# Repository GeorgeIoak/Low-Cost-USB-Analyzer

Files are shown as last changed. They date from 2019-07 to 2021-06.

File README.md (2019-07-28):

# Low Cost High Speed USB Analyzer
This project originated starting from a comment made by Kate Temkin (@ktemkin) with the idea to design a very low cost USB analyzer that was capable of achieving HS (High Speed). The [NXP LPC4357 MCU (32-bit ARM Cortex-M4/M0 MCU)](https://www.nxp.com/docs/en/data-sheet/LPC435X_3X_2X_1X.pdf) can operate at up to 204MHz and has (among other things) a ULPI interface. The [Microchip USB3343](http://ww1.microchip.com/downloads/en/DeviceDoc/USB334x-Data-Sheet-DS00002646A.pdf) is used as the interface between the USB device to test and the LPC4357. The LPC4357 has a 2nd HS USB port that can connect to a PC for USB traffic analysis. The board also includes a 256Mb SDR SDRAM.

In order to keep costs down the size of the board was fixed at 50mm x 50mm and 4 layers. This is far from ideal when doing a controlled impedance design with this many signals so there are some tradeoffs. I didn't want to waste all of the processing capabilities so I managed to bring out ALL of the LPC4357 signals to 1.27mm pitch headers around the perimiter of the PCB. The 24-bit LCD interface signals are all on 1 header and the Ethernet signals are all on another header.

This is NOT a finished project but it is getting close. The design in done in Altium but I am going to try and convert the design to KiCad once it gets closer to being finished

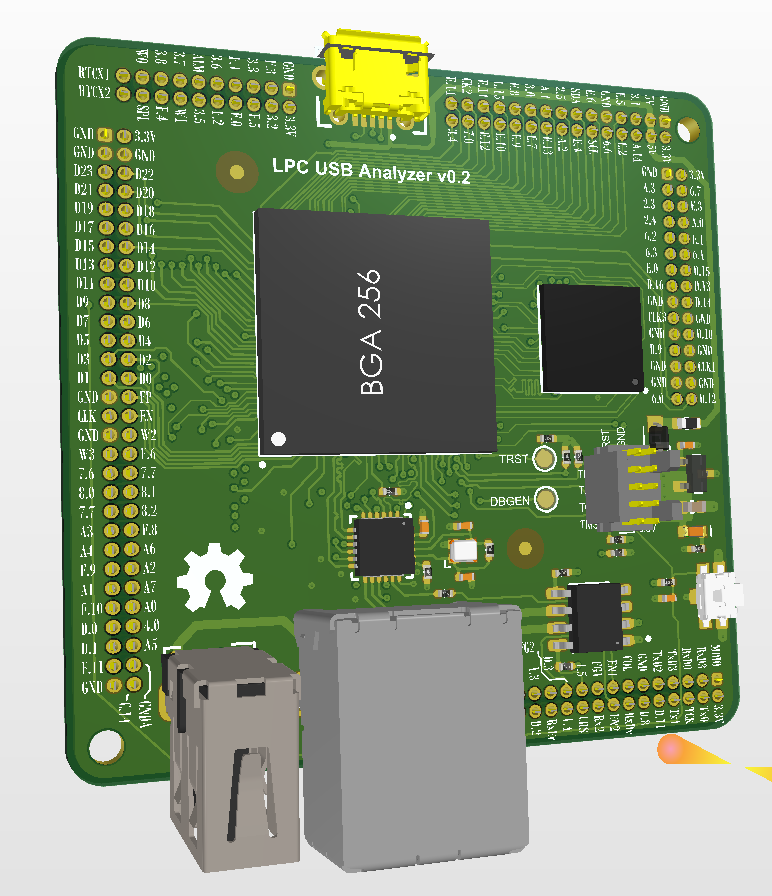
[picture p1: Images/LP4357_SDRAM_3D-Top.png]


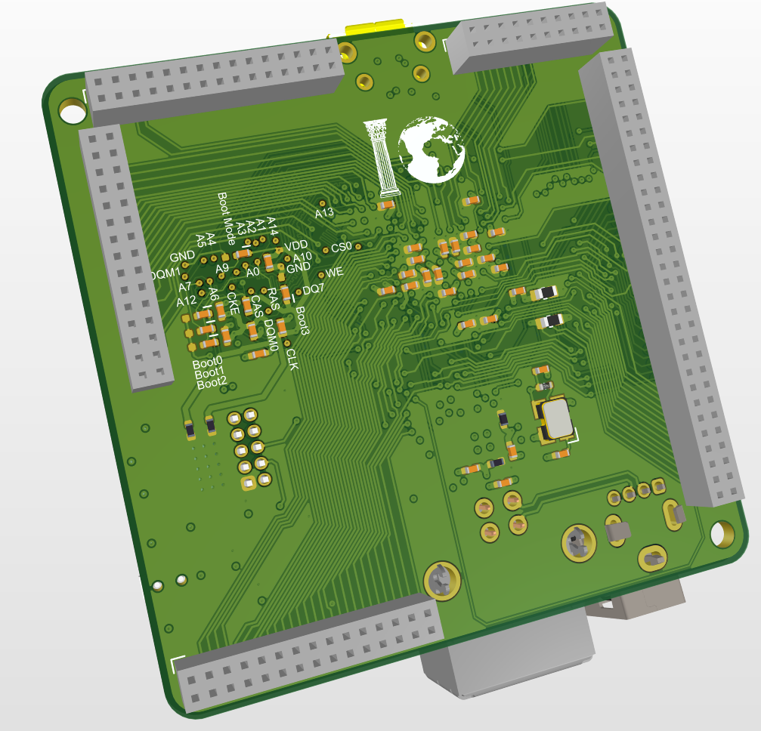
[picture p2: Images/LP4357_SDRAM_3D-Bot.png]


You can download the "LPC4357_SDRAM-BGA Design Files.zip" file and use [Altium's Online Viewer](https://www.altium.com/viewer?utm_content=buffer67ff0) to look through the schematic and layout

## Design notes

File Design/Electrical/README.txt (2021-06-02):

R1 and R11 were purchased as 8.06Ω instead of 8.06kΩ so the prototypes were built with the wrong part.

R1 is on the RBIAS pin of the USB3343 so that's important to change
R11 is just LED series resistor for 3.3V power indicator

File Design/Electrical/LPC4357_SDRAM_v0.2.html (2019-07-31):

Altium customize

# Board Information Report

Date: | | 7/30/2019
Time: | | 5:17:31 PM
Elapsed Time: | | 00:00:00
Filename: | | C:\Users\georg\Dropbox\Design\LPC4357_SDRAM\Design\Electrical\LPC4357_SDRAM_v0.2.PcbDoc
Units: | | mmmils

## Contents

Contents

Board Specification

General

Routing

Routing Information

Layer Information

Layer Information

Drill Pairs

Board Holes

Non-Plated Hole Size

Plated Hole Size

Board Slots

Non-Plated Slot Size

Plated Slot Size

Board Square Holes

Non-Plated Square Hole Size

Plated Square Hole Size

Other

Top Layer Annular Ring Size

Mid Layer Annular Ring Size

Bottom Layer Annular Ring Size

Pad Solder Mask

Pad Paste Mask

Pad Pwr/Gnd Expansion

Pad Relief Conductor Width

Pad Relief Air Gap

Pad Relief Entries

Via Solder Mask

Via Pwr/Gnd Expansion

Track Width

Arc Line Width

Arc Radius

Arc Degrees

Text Height

Text Width

Net Track Width

Net Via Size

## Board Specification

General
Board Size | 50mm x 50mm
Components on board | 90

Back to top

## Routing

Routing Information
Routing completion | 100.00%
Connections | 472
Connections routed | 472
Connections remaining | 0

Back to top

## Layer Information

Layer | Arcs | Pads | Vias | Tracks | Texts | Fills | Regions | ComponentBodies
Top Layer | 65 | 412 | 0 | 1606 | 0 | 1 | 485 | 0
Int1 (GND) | 0 | 0 | 0 | 0 | 0 | 0 | 1 | 0
Int2 (PWR) | 414 | 0 | 0 | 1209 | 0 | 0 | 135 | 0
Bottom Layer | 0 | 101 | 0 | 1342 | 0 | 0 | 328 | 0
Board Outline | 4 | 0 | 0 | 4 | 0 | 0 | 0 | 2
Top 3D Bodies | 2 | 0 | 0 | 17 | 0 | 0 | 0 | 80
Mechanical 12 | 0 | 0 | 0 | 0 | 0 | 0 | 0 | 0
Mechanical 13 | 4 | 0 | 0 | 269 | 1 | 0 | 0 | 5
Mechanical 15 | 2 | 0 | 0 | 469 | 2 | 0 | 0 | 1
Mechanical 16 | 0 | 0 | 0 | 2 | 0 | 0 | 0 | 0
Mechanical 22 | 0 | 0 | 0 | 0 | 0 | 0 | 0 | 0
Multi-Layer | 0 | 201 | 346 | 0 | 0 | 0 | 1 | 0
Top Paste | 0 | 0 | 0 | 0 | 0 | 9 | 0 | 0
Top Overlay | 8 | 0 | 0 | 83 | 255 | 0 | 2 | 0
Top Solder | 0 | 0 | 0 | 0 | 0 | 0 | 0 | 0
Bottom Solder | 0 | 0 | 0 | 0 | 0 | 0 | 0 | 0
Bottom Overlay | 0 | 0 | 0 | 3043 | 135 | 0 | 0 | 0
Bottom Paste | 0 | 0 | 0 | 0 | 0 | 0 | 0 | 0
Drill Guide | 0 | 0 | 0 | 0 | 0 | 0 | 0 | 0
Keep-Out Layer | 4 | 0 | 0 | 4 | 0 | 0 | 0 | 0
Drill Drawing | 0 | 0 | 0 | 173 | 104 | 0 | 0 | 0
Total | 503 | 714 | 346 | 8221 | 497 | 10 | 952 | 88

Back to top

Drill Pairs | Vias
Top Layer - Bottom Layer | 346
Total | 346

Back to top

## Board Holes

Non-Plated Hole Size | Pads | Vias
0mm | 13 | 0
Total | 13 | 0

Back to top

Plated Hole Size | Pads | Vias
0mm | 500 | 0
0.2mm | 0 | 327
0.25mm | 0 | 15
0.3mm | 0 | 4
0.6mm | 170 | 0
0.7mm | 12 | 0
0.8mm | 4 | 0
0.9mm | 2 | 0
0.92mm | 4 | 0
1.2mm | 2 | 0
2mm | 1 | 0
2.2mm | 1 | 0
2.3mm | 2 | 0
Total | 698 | 346

Back to top

## Board Slots

Non-Plated Slot Size / Length | Pads
Total | 0

Back to top

Plated Slot Size / Length | Pads
23.622mil / 70.866mil | 2
39.37mil / 62.992mil | 1
Total | 3

Back to top

## Board Square Holes

Non-Plated Square Hole Size | Pads
Total | 0

Back to top

Plated Square Hole Size | Pads
Total | 0

Back to top

## Other

Top Layer Annular Ring Size | Count
-10.7mm | 2
-1.2mm | 1
-1mm | 1
0.2mm | 4
0.25mm | 352
0.3mm | 4
0.3mm | 170
0.497mm | 2
0.58mm | 4
0.6mm | 2
0.7mm | 2
1.6mm | 1
2mm | 2
Total | 547

Back to top

Mid Layer Annular Ring Size | Count
-10.7mm | 2
-1.2mm | 1
-1mm | 1
0.2mm | 4
0.25mm | 352
0.3mm | 4
0.3mm | 170
0.497mm | 2
0.58mm | 4
0.6mm | 2
0.7mm | 2
1.6mm | 1
2mm | 2
Total | 547

Back to top

Bottom Layer Annular Ring Size | Count
-10.7mm | 2
-1.2mm | 1
-1mm | 1
0.2mm | 4
0.25mm | 352
0.3mm | 4
0.3mm | 170
0.497mm | 2
0.58mm | 4
0.6mm | 2
0.7mm | 2
1.6mm | 1
2mm | 2
Total | 547

Back to top

Pad Solder Mask | Count
0mm | 13
0.0508mm | 16
0.065mm | 24
0.07mm | 11
0.075mm | 310
0.09mm | 4
0.095mm | 4
0.1016mm | 330
1mm | 2
Total | 714

Back to top

Pad Paste Mask | Count
-10mm | 1
-2mm | 2
0mm | 709
0.1mm | 2
Total | 714

Back to top

Pad Pwr/Gnd Expansion | Count
0.508mm | 714
Total | 714

Back to top

Pad Relief Conductor Width | Count
0.254mm | 714
Total | 714

Back to top

Pad Relief Air Gap | Count
0.254mm | 714
Total | 714

Back to top

Pad Relief Entries | Count
4 | 714
Total | 714

Back to top

Via Solder Mask | Count
0.07mm | 4
0.1016mm | 342
Total | 346

Back to top

Via Pwr/Gnd Expansion | Count
0.508mm | 346
Total | 346

Back to top

Track Width | Count
0.01mm | 4
0.05mm | 264
0.0508mm | 3021
0.1mm | 1565
0.1016mm | 14
0.11mm | 595
0.127mm | 153
0.15mm | 774
0.152mm | 712
0.1524mm | 380
0.1778mm | 63
0.2mm | 26
0.2032mm | 167
0.254mm | 24
0.3mm | 25
0.4mm | 125
0.45mm | 237
0.452mm | 6
0.5mm | 39
0.508mm | 6
0.55mm | 1
0.6mm | 10
0.762mm | 4
0.8mm | 5
1mm | 1
Total | 8221

Back to top

Arc Line Width | Count
0.01mm | 2
0.0762mm | 2
0.1mm | 412
0.11mm | 44
0.127mm | 4
0.152mm | 29
0.25mm | 5
0.6mm | 1
0.762mm | 4
Total | 503

Back to top

Arc Radius | Count
0.0196mm | 2
0.03mm | 1
0.0301mm | 1
0.04mm | 318
0.044mm | 23
0.0504mm | 20
0.052mm | 10
0.0608mm | 29
0.069mm | 30
0.0704mm | 45
0.0911mm | 1
0.125mm | 4
0.3mm | 3
0.5mm | 4
0.635mm | 2
0.91mm | 2
2.5mm | 6
2.5mm | 2
Total | 503

Back to top

Arc Degrees | Count
78 | 2
90 | 487
360 | 14
Total | 503

Back to top

Text Height | Count
0.75mm | 1
0.762mm | 1
1mm | 121
1.4mm | 170
1.5mm | 1
1.524mm | 200
1.5494mm | 2
5mm | 1
Total | 497

Back to top

Text Width | Count
0.075mm | 1
0.127mm | 1
0.2032mm | 185
0.254mm | 310
Total | 497

Back to top

Net Track Width | Count
0.089mm | 229
0.254mm | 4
Total | 233

Back to top

Net Via Size | Count
0.45mm | 233
Total | 233

Back to top

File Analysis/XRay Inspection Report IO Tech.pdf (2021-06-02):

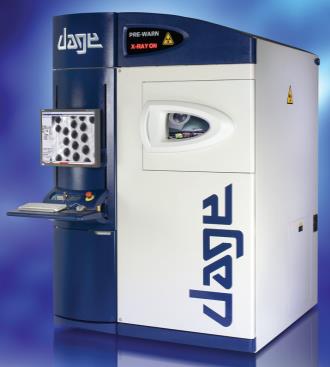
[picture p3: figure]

# X-Ray Inspection Report

Customer: | I/O SAFE

Work Order:

Assembly No:

Serial No:

Scope of work: | Inspecting BGA Balls
Engineer: | Victor Dallago
Date: | 08/15/2019
Observation/Conclusions | Varying size and shape of BGA balls caused by design of BGA pad layout

10030 Foothills Blvd.
Roseville, CA 95747
(800) 550-6005
www.prideindustries.com

# I/O SAFE

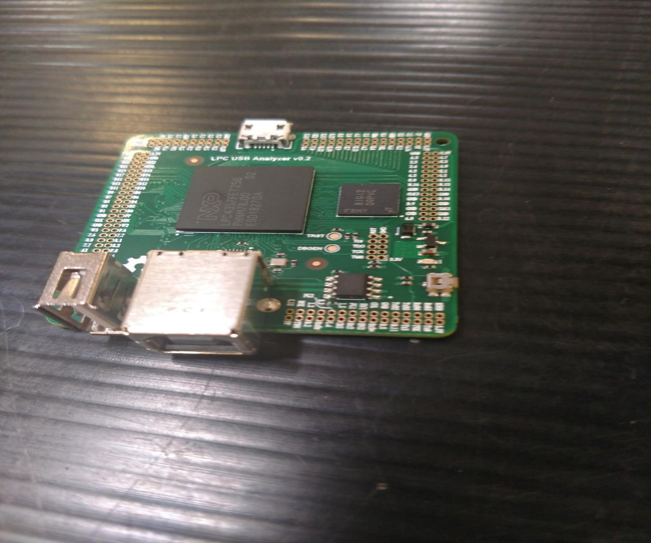
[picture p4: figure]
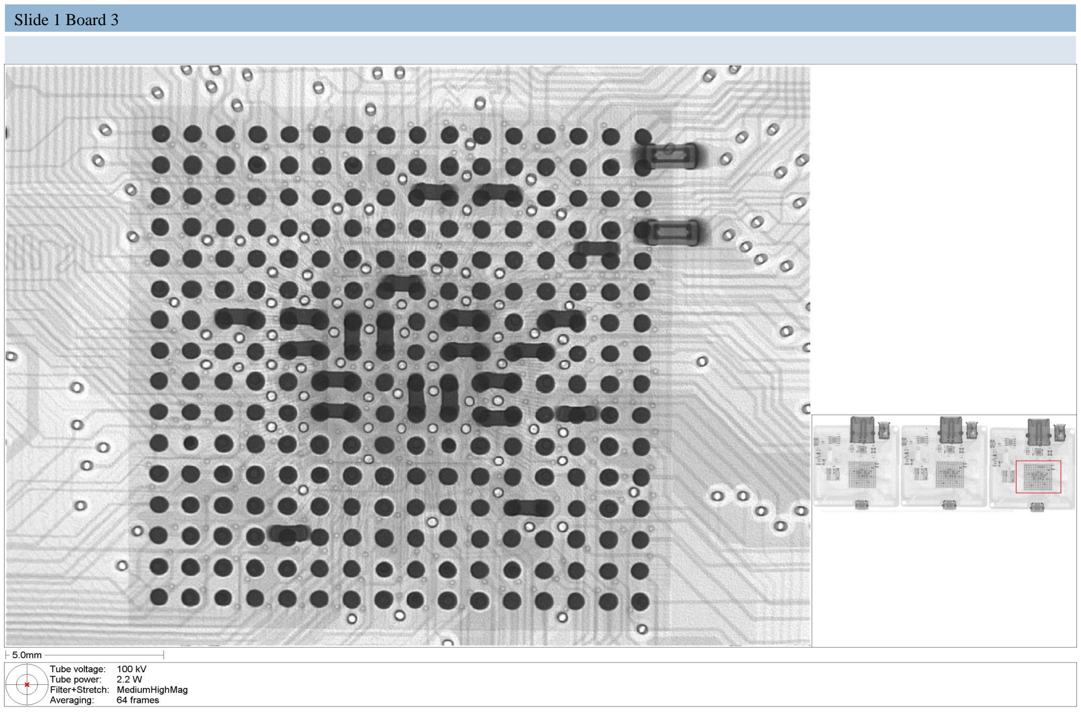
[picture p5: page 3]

Slide 1 Board 3

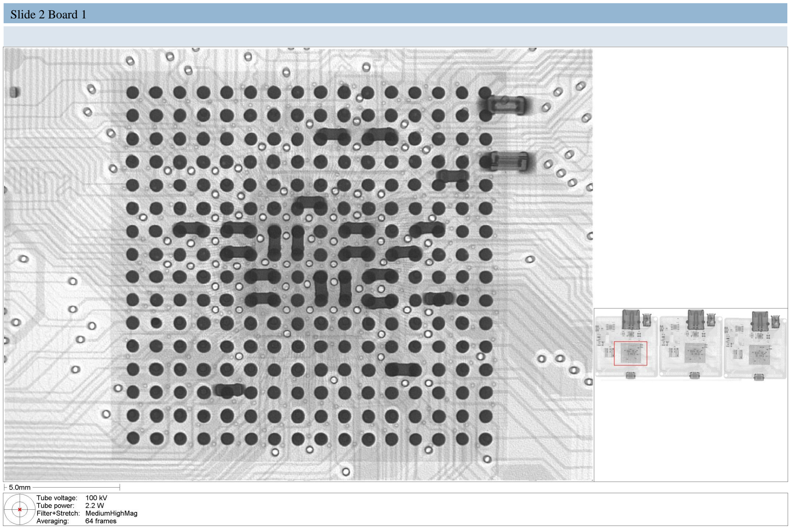
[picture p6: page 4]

Slide 2 Board 1

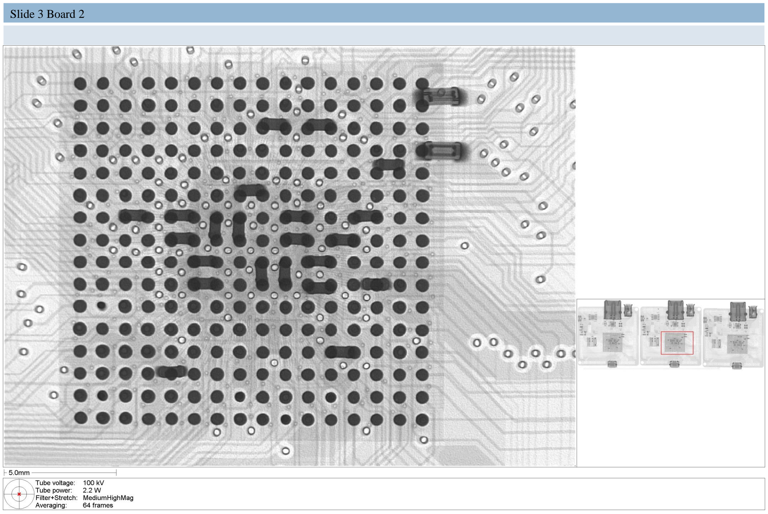
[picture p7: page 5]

Slide 3 Board 2

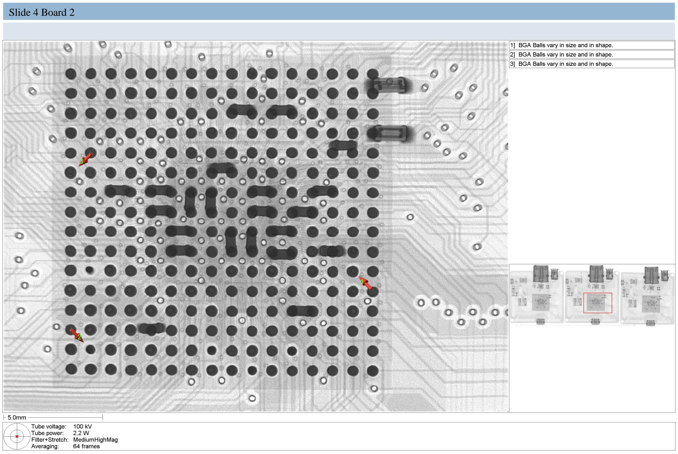
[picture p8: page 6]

Slide 4 Board 2

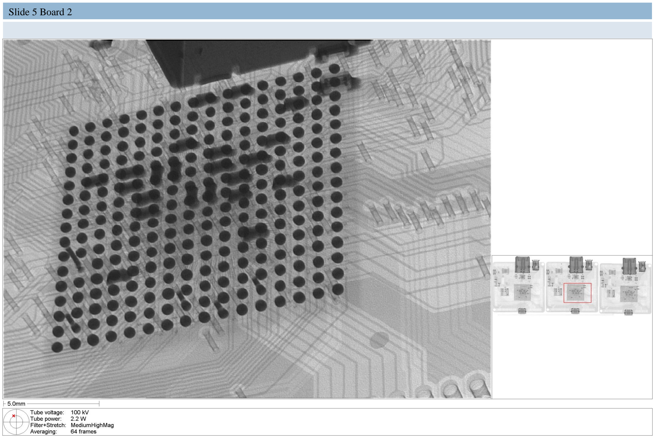
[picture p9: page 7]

Slide 5 Board 2

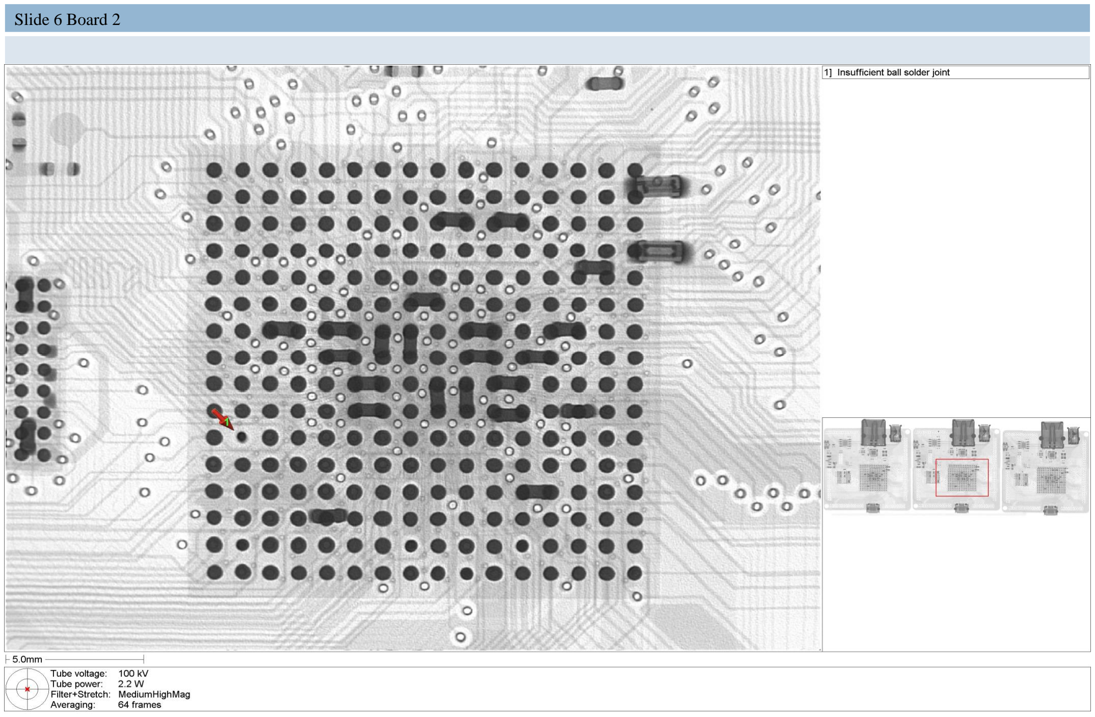
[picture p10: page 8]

Slide 6 Board 2

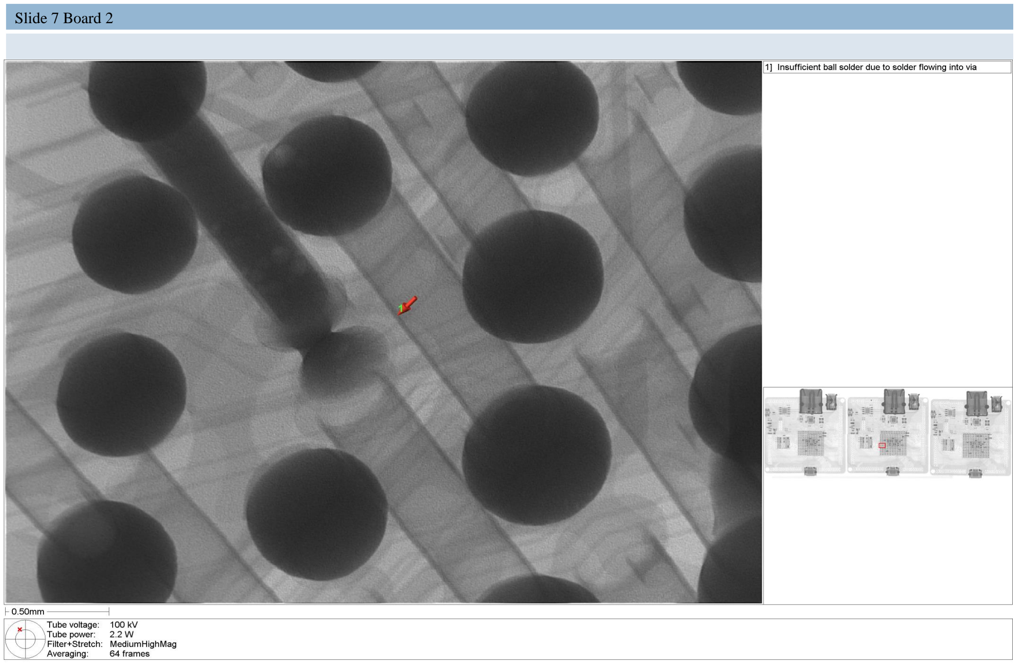
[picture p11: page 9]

Slide 7 Board 2

# 3D X-Ray Solutions

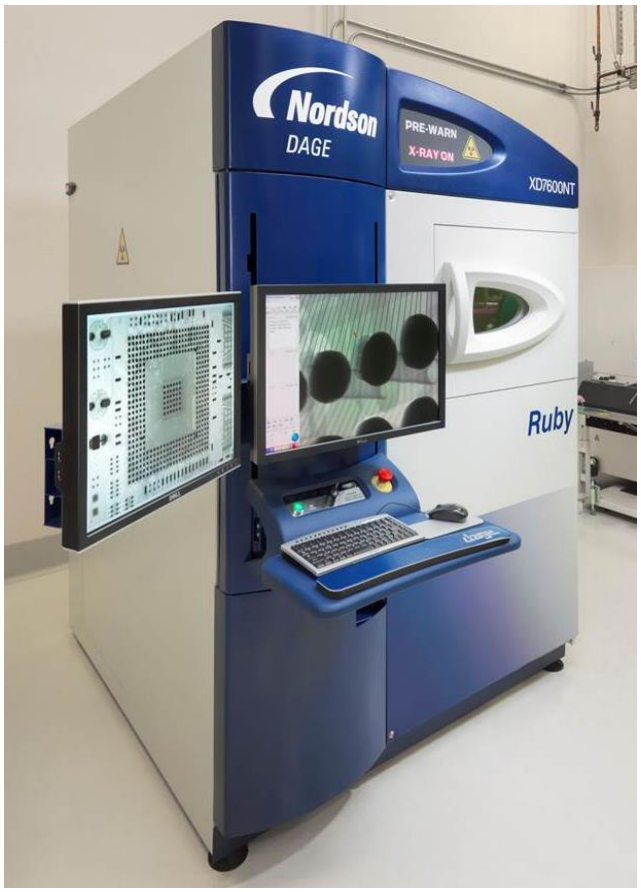
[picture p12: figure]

The Nordson DAGE XD7600NT Ruby X-ray is the ultimate inspection system. The inspection system uses the latest technology image intensifier and proven feature recognition capability to provide the ultimate choice for the highest quality in X-ray imaging on the market today. With the revolutionary X-Plane™ option, the superior image quality can be extended into separating individual layers. X-Plane™ uses a proprietary, patent applied for tomosynthesis or CT technique to create 2-D X-ray slices in any plane of a printed circuit board assembly without the need to cut or destroy the board. Specifications:
- Proveable < 0.5 µm Feature Recognition
- 160 kV Tube with Up to 10 W Tube Power
- 1,800 X geometric magnification
- 23,400 X total magnification including digital zoom
- Maximum board size: 29” x 22.8” (736 x 580 mm)
- Maximum inspection area: 20” x 17.5” (508 x 444 mm)
- 70° oblique angle views for 360° around a point of interest
- AciS - Active X-ray Image Stabilisation - anti-vibration control
- ciDAT3 digital image intensifier detector with 1600 x 1200 pixels (2.0 Mpixels):
- X-Plane™
(800) 550-6005
info@prideindustries.com

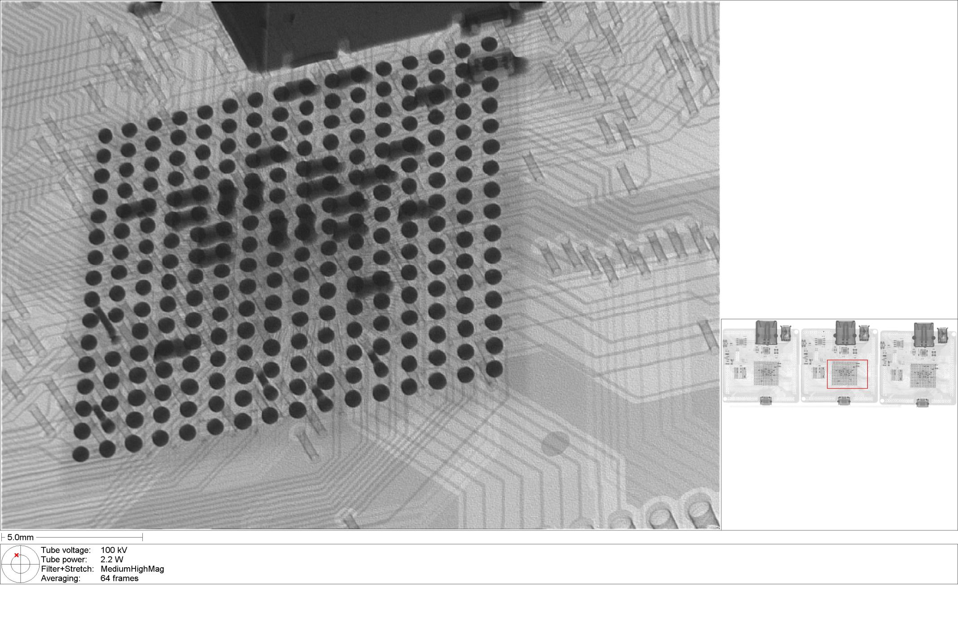
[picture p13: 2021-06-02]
Analysis/Board2_Xray_Angle.png

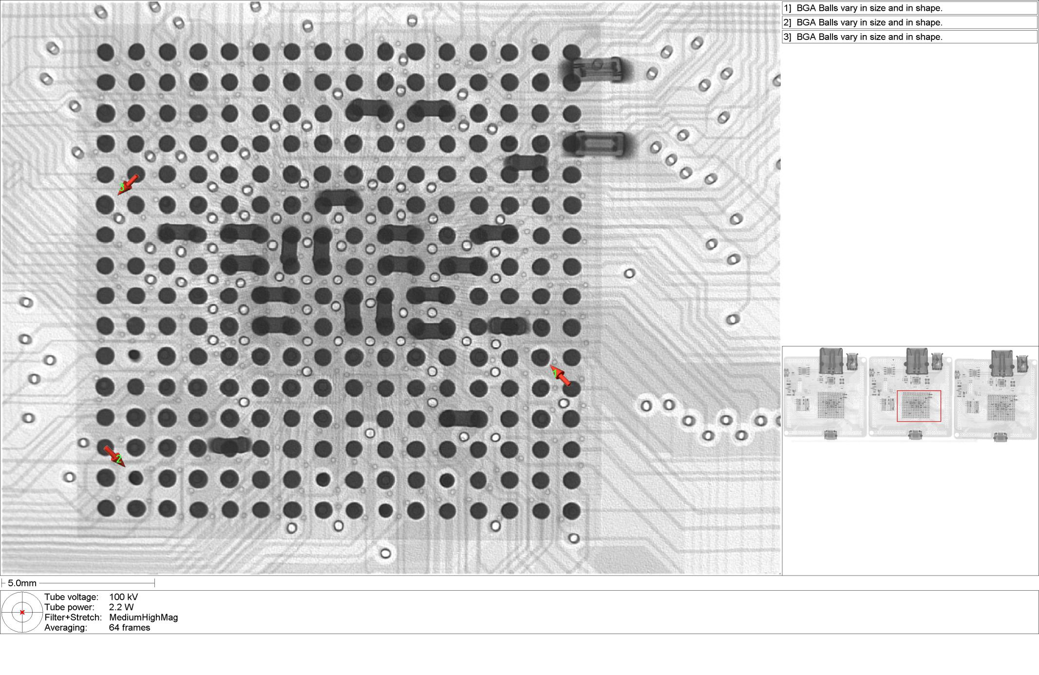
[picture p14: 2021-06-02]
Analysis/Board2_Xray_Top2.png

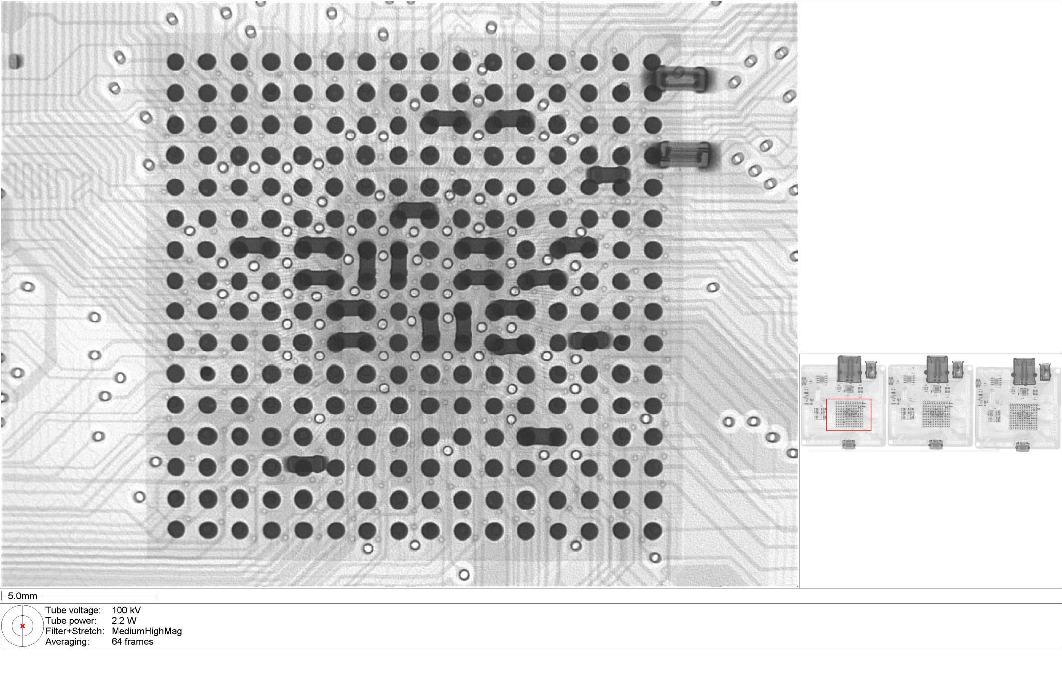
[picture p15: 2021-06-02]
Analysis/Board1_Xray_Top.png

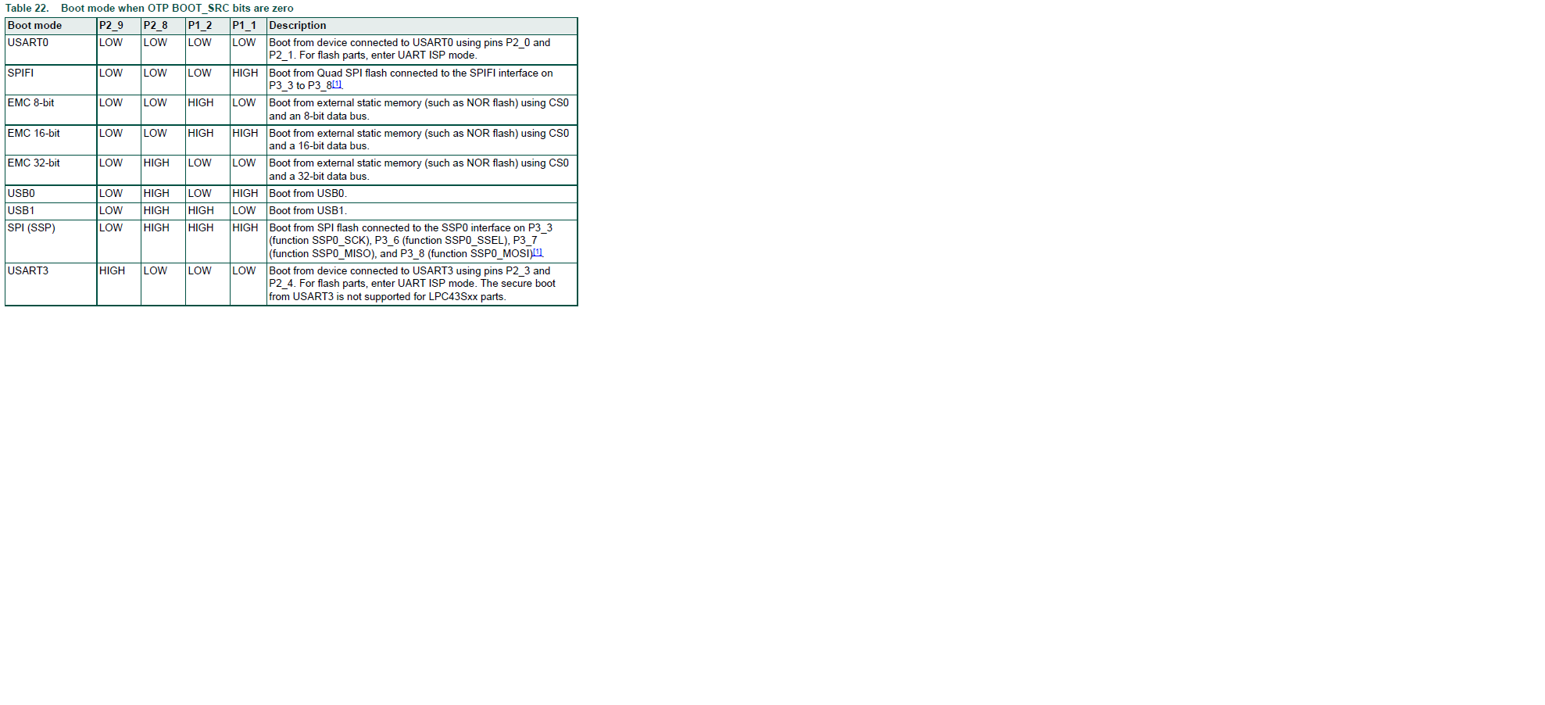
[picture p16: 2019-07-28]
Reference/Boot Pin Settings.png

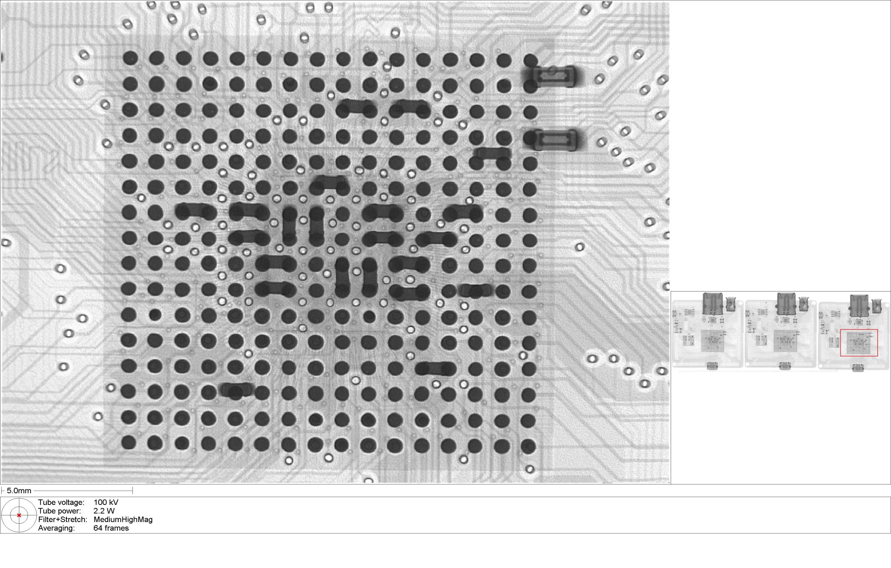
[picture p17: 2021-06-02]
Analysis/Board3_Xray_Top.png

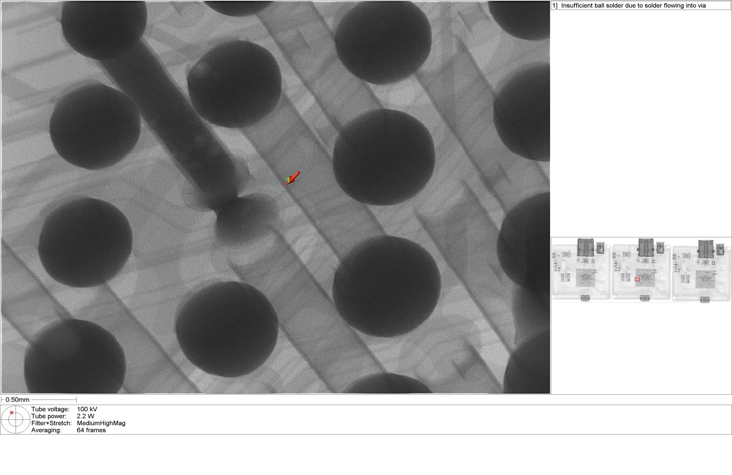
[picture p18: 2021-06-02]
Analysis/Board2_Xray_Angle2.png

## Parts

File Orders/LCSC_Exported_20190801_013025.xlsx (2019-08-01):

LCSC Part Number | Manufacture Part Number | Manufacturer | Customer NO. | Package | Description | RoHS | Order Qty. | Min\Mult Order Qty. | Unit Price | Order Price
C6846 | SN74HC374NSR | Texas Instruments |  | SOIC-20_208mil | Flip Flops SOIC-20_208mil RoHS | Yes | 2 | 1\1 | $0.8136 | $1.63
C39452 | - | Jing Extension of the Electronic Co. |  | Side insert | USB Connectors 4 Receptacle 1 Side insert RoHS | Yes | 50 | 5\5 | $0.0477 | $2.39
C60490 | RC0402FR-0710KL | YAGEO |  | 0402 | Chip Resistor - Surface Mount 10KOhms ±1% 1/16W 0402 RoHS | Yes | 1000 | 100\100 | $0.0004 | $0.4
C73936 | ULN2803A | STMicroelectronics |  | DIP-18 | Darlington transistor array driver DIP-18 RoHS | Yes | 2 | 1\1 | $0.5652 | $1.14
C93942 | RC0402FR-0720KL | YAGEO |  | 0402 | Chip Resistor - Surface Mount 20KOhms ±1% 1/16W 0402 RoHS | Yes | 1000 | 100\100 | $0.0018 | $1.8
C114760 | RC0402FR-0712KL | YAGEO |  | 0402 | Chip Resistor - Surface Mount 12KOhms ±1% 1/16W 0402 RoHS | Yes | 1000 | 100\100 | $0.0004 | $0.4
C125098 | LTST-C191KGKT | Lite-On |  | 0603 | Light Emitting Diodes (LED) Green 567.5~576.5nm 18~71mcd@20mA Top View 0603 RoHS | Yes | 200 | 20\20 | $0.0128 | $2.56
C131394 | CC0402KRX7R9BB104 | YAGEO |  | 0402 | Multilayer Ceramic Capacitors MLCC - SMD/SMT 100nF 50V 0402 RoHS | Yes | 1000 | 50\50 | $0.0031 | $3.1
C132563 | 10118194-0001LF | Amphenol ICC |  | SMD | USB Connectors 5 Receptacle 1 SMD RoHS | Yes | 10 | 1\1 | $0.3379 | $3.38
C133334 | SMD-3225_4P12M20pf10ppm | Zhejiang Abel Elec |  | SMD-3225_4P | SMD Crystal Resonators 12MHz ±10ppm SMD-3225_4P RoHS | Yes | 20 | 5\5 | $0.1036 | $2.08
C136064 | X2C026000B91H-V | Harmony Elec |  | SMD-2016_4P | SMD Crystal Resonators 26MHz ±10ppm SMD-2016_4P RoHS | Yes | 20 | 1\1 | $0.1167 | $2.34
C137928 | RC0402FR-078R06L | YAGEO |  | 0402 | Chip Resistor - Surface Mount 8.06Ohms ±1% 1/16W 0402 RoHS | Yes | 1000 | 100\100 | $0.0019 | $1.9
C138033 | RC0402FR-071ML | YAGEO |  | 0402 | Chip Resistor - Surface Mount 1MOhms ±1% 1/16W 0402 RoHS | Yes | 1000 | 100\100 | $0.0004 | $0.4
C150746 | AP7333-33SAG-7 | Diodes Incorporated |  | SOT-23(SOT-23-3) | Low Dropout Regulators(LDO) SOT-23(SOT-23-3) RoHS | Yes | 20 | 1\1 | $0.1030 | $2.06
C155322 | AP2192ASG-13 | Diodes Incorporated |  | SOIC-8_150mil | PMIC - Power Distribution Switches SOIC-8_150mil RoHS | Yes | 5 | 1\1 | $1.0439 | $5.22
C221906 | PTS840GKPSMTRLFS | C&K |  | 3.5mm*3.55mm | Tactile Switches SPST-NO 3.55mm x 3.50mm 50mA @ 12VDC 3.5mm*3.55mm RoHS | Yes | 20 | 1\1 | $0.1742 | $3.49
C307443 | CL05C180JB5NNNC | Samsung Electro-Mechanics |  | 0402 | Multilayer Ceramic Capacitors MLCC - SMD/SMT 18pF 50V 0402 RoHS | Yes | 100 | 50\50 | $0.0036 | $0.36
C344022 | GRM188R61E106KA73D | Murata Electronics |  | 0603 | Multilayer Ceramic Capacitors MLCC - SMD/SMT 10uF 25V 0603 RoHS | Yes | 50 | 5\5 | $0.0401 | $2.01

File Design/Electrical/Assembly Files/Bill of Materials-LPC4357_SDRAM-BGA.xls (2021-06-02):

Quantity | Designator | Comment | Description | Manufacturer | Manufacturer_No | Supplier 1 | Supplier Part Number 1 | Manufacturer 1 | Manufacturer Part Number 1
32 | C1, C2, C3, C4, C5, C6, C7, C8, C9, C10, C11, C12, C13, C14, C15, C16, C17, C18, C19, C20, C21, C22, C23, C26, C27, C28, C29, C30, C31, C32, C33, C36 | 100n | Cap, Chip, 100nF, 16V, ±10%, X7R, 0402 | NIC | NMC0402X7R104K16TRPF | Arrow | NMC0402X7R104K16TRPF | NIC Components | NMC0402X7R104K16TRPF
3 | C24, C25, C39 | 1u | Cap, Chip, 1uF, 10V, ±10%, X5R, 0402 | NIC | NMC0402X5R105K10TRPF | Arrow | NMC0402X5R105K10TRPF | NIC Components | NMC0402X5R105K10TRPF
4 | C34, C35, C37, C38 | 18p | Cap, Chip, 18pF, 50V, ±10%, NPO 0402 | NIC | NMC0402NPO180J50TRPF | Arrow | NMC0402NPO180J50TRPF | NIC Components | NMC0402NPO180J50TRPF
1 | C40 | 10u | Cap, Chip, 10uF, 10V, ± 15%, X5R, 0603 | NIC | NMC0603X5R106K10TRPF | Arrow | NMC0603X5R106K10TRPF | NIC Components | NMC0603X5R106K10TRPF
1 | D1 | PMEG2015EH | Diode, Schottky Rectifier, 20V, 1.5A, SOT123F | NXP | PMEG2015EH T/R | Digi-Key | 1727-3860-6-ND | Nexperia | PMEG2015EH,115
1 | D2 | 0603 Green | 0603 LED, Green | Lite-on | LTST-C190KGKT | Digi-Key | 160-1435-6-ND | Vishay Lite-On | LTST-C190KGKT
3 | FB1, FB2, FB3 | 120R | Ferrite bead,120 ohm@100MHz,0.30 ohm @DC, 500mA, 0603 | NIC | NCB0603R121TR060F | Arrow | NCB0603R121TR060F | NIC Components | NCB0603R121TR060F
4 | FB4, FB5, FB6, FB7 | 300R | Ferrite bead,300 ohm@100MHz,0.15 ohm @DC, 1A, 0402 | NIC | NCB-H0402P301TR100F | Digi-Key | 490-5256-2-ND | Murata | BLM18KG331SN1D
1 | H1 | 2x30 | CONN, Header, 2x30, TH, 1.27mm | Shenzhen Cankemeng | 220-1S-2*30 | LCSC | C124402 | Shenzhen Cankemeng | 220-1S-230XP
1 | H2 | 2x10 | CONN, Header, 2x10, TH, 1.27mm |  |  | LCSC | C350287 | HOAUC | 2343U-205CNG1SNT01
3 | H3, H4, H5 | 2x15 | CONN, Header, 2x15, TH, 1.27mm |  |  | Digi-Key | 609-3763-ND | Amphenol FCI | 20021311-00030T4LF
1 | H6 | JTAG | CONN, Header 2x5, TH, 1.27mm | Samtec | FTSH-105-01-L-D-K | Digi-Key | SAM8798-ND | Samtec | FTSH-105-01-L-D-K
1 | J1 | Type A | USB 2.0, Type A, Side Insert, Reverse Pinout, RA, TH | Jing Extension | C39452 | LCSC | C39452 | Jing Extension of the Electronic Co. | C39452
1 | J2 | micro USB B | USB 2.0, Micro USB, 5-pin, RA, SMT/TH | FCI | 10118194 | Digi-Key | 609-4618-1-ND | Amphenol FCI | 10118194-0001LF
1 | J3 | Type B | USB 2.0, Type B, RA, TH | FCI | 61729-1011BLF | Avnet | 61729-1011BLF | AMPHENOL ICC (FCI) | 61729-1011BLF
1 | PCB | LPC USB Analyzer v0.2 | 4 Layer Controlled Impedance PCB, ENIG | JLCPCB |  | JLCPCB | IOT-5555 | JLCPCB | IOT-5555
2 | R1, R11 | 8.06k | Resistor, 8.06 kΩ, 1%, 0.06W, 0402 | NIC | NRC04F8061TRF | Arrow | NRC04F8061TRF | NIC Components | NRC04F8061TRF
2 | R2, R9 | 1M | Resistor, 1 MΩ, 1%, 0.06W, 0402 | NIC | NRC04F1004TRF | Arrow | NRC04F1004TRF | NIC Components | NRC04F1004TRF
8 | R3, R4, R5, R6, R7, R8, R13, R14 | 10k0 | Resistor, 10.0 kΩ, 1%, 0.06W, 0402 | NIC | NRC04F1002TRF | Arrow | NRC04F1002TRF | NIC Components | NRC04F1002TRF
1 | R10 | 12k0 | Resistor, 12.0 kΩ, 1%, 0.06W, 0402 | NIC | NRC04F1202TRF | Arrow | NRC04F1202TRF | NIC Components | NRC04F1202TRF
1 | R12 | 20k0 | Resistor, 20 kΩ, 1%, 0.06W, 0402 | NIC | NRC06F2002TRF | Arrow | NRC06F2002TRF | NIC Components | NRC06F2002TRF
1 | R15 | BOOT_3 | 3-pad, 0402, jumper
1 | R16 | BOOT_2 | 3-pad, 0402, jumper
1 | R17 | BOOT_1 | 3-pad, 0402, jumper
1 | R18 | BOOT_0 | 3-pad, 0402, jumper
1 | R19 | BOOT MODE | 3-pad, 0402, jumper
1 | S1 | PTS840 | SWITCH SPST RA, 50mA, 24V, SMT | C&K | PTS840 GKP SMTR LFS | Digi-Key | CKN10514CT-ND | ITT C&K | PTS840GKPSMTRLFS
1 | U1 | LPC4357JET256,551 | 32-bit ARM Cortex-M4 / M0 MCU, 164 I/O, 1024 KB Flash, 136 KB SRAM, LBGA-256 | NXP | LPC4357JET256,551 | Arrow | LPC4357JET256,551 | NXP Semiconductors | LPC4357JET256,551
1 | U2 | MT48LC16M16A2B4-6A:G | 256Mb 167MHz SDR SDRAM, 16Mb x 16, 5.4ns, 3.3V, VFBGA-54, 8x8 | Micron | MT48LC16M16A2B4-6A AIT:G TR | Avnet | MT48LC16M16A2B4-6A:G | Micron Technology | MT48LC16M16A2B4-6A:G
1 | U3 | USB3343-CP-TR | Hi-Speed USB ULPI Transceiver, 1.8 to 3.3 V, QFN-24 | Microchip | USB3343-CP-TR‎ | Digi-Key | 638-1116-6-ND | Microchip | USB3343-CP-TR
1 | U4 | AP7333-33SAG-7 | IC, CONV DC/DC LDO 3.3V, 300mA, SOT23-3 | STMicro | LD1117S33CTR | Digi-Key | 497-1241-6-ND | STMicroelectronics | LD1117S33CTR
1 | U5 | AP2192A | IC, USB Dual Switch w/ 1.5A Current Limit, SOIC-8 | Diodes Inc | AP2192ASG-13 | Digi-Key | AP2192ASG-13DICT-ND | Diodes | AP2192ASG-13
1 | X1 | 12MHz | X-tal, 12.000MHz, Cl=20pF, +-18ppm, 3225 | ABRACON Co | ABM8G-12.000MHZ-B4Y-T | Digi-Key | 535-10283-1-ND | Abracon | ABM8G-12.000MHZ-B4Y-T
1 | X2 | 26MHz | X-tal, 26.000MHz, Cl=6pF, +-18ppm, 2.0 x 1.6mm | muRata | XRCGB26M000F2P00R0 | Digi-Key | 490-9764-1-ND | Murata | XRCGB26M000F2P00R0

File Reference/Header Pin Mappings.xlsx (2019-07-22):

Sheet: parametric-data
Part number | Vin (Min) (V) | Vin (Max) (V) | Continuous current (Max) (A) | Current limit (A) | Enable
LM3526 - Dual Port USB Power Switch and Over-current Protection | 2.7 | 5.5 | 0.5 | 1.9 | Active High, Active Low
TPS2002C - Dual-Channel, Current-Limited, Power-Distribution Switch | 4.5 | 5.5 | 2 | 2.35 to 3.95 | Active Low | 0.69 | 250 | VSON10 | stock
TPS2003C - Dual-Channel, Current-Limited, Power-Distribution Switch | 4.5 | 5.5 | 2 | 2.35 to 3.95 | Active High | 0.69 | 250 | VSON10 | no stock
TPS2042B - Dual, Current-Limited, Power-Distribution Switches | 2.7 | 5.5 | 0.5 | 1 | Active Low | 0.73 | 250 | SON8 | stock
TPS2046B - Current-Limited Power-Distribution Switches | 2.7 | 5.5 | 0.25 | 0.5 | Active Low |  |  | SOIC
TPS2052B - Current-Limited, Power-Distribution Switches | 2.7 | 5.5 | 0.5 | 1 | Active High | 0.73 | 250 | SON8 | stock
TPS2052C - Dual Channel, Current-Limited USB Power Distribution Switch | 4.5 | 5.5 | 0.5 | 0.7 to 1.3 | Active High |  |  | MSOP
TPS2056A - 0.345A, 2.7-5.5V Dual (1In/2Out) Hi-Side MOSFET, Fault Report, Act-High Enable | 2.7 | 5.5 | 0.25 | 0.5 | Active High |  |  | SOIC
TPS2060 - Dual 1.5A Current-Limited, Power Distribution Switch | 2.7 | 5.5 | 1.5 | 2.1 | Active Low | 1.04 | 250 | SON8 | stock
TPS2060C - Dual-Channel, Current-Limited, Power-Distribution Switch | 4.5 | 5.5 | 1.5 | 1.72 to 2.86 | Active Low |  |  | MSOP
TPS2062 - Dual 1A Current-Limited, Power-Distribution Switches | 2.7 | 5.5 | 1 | 1.5 | Active Low |  |  | MSOP
TPS2062-1 - Current-Limited, Power-Distribution Switches with Output Discharge resistor | 2.7 | 5.5 | 1 | 1.5 | Active Low
TPS2062A - Current-limited, Power Distribution Switches | 2.7 | 5.5 | 1 | 1.9 | Active Low | 0.81 |  | SON8 | no stock
TPS2062C - Dual-Channel, Current-Limited, Power-Distribution Switch | 4.5 | 5.5 | 1 | 1.12 to 2.10 | Active Low |  |  | MSOP
TPS2062C-2 - Dual Channel Current Limiting Switch | 4.5 | 5.5 | 1 | 1.6 | Active Low | 0.69 | 250 | SON8 | good stock
TPS2064 - Dual 1.5A Current-Limited, Power Distribution Switch | 2.7 | 5.5 | 1.5 | 2.1 | Active High | 1.04 | 250 | SON8 | stock
TPS2064C - Dual-Channel, Current-Limited, Power-Distribution Switch | 4.5 | 5.5 | 1.5 | 1.72 to 2.86 | Active High |  |  | MSOP
TPS2064C-2 - Dual Channel Current Limiting Switch | 4.5 | 5.5 | 1.5 | 2.29 | Active High |  |  | MSOP
TPS2066 - Dual 1A Current-Limited, Power-Distribution Switches | 2.7 | 5.5 | 1 | 1.5 | Active High |  |  | SOIC
TPS2066-1 - Current-Limited, Power-Distribution Switches with Output Discharge resistor | 2.7 | 5.5 | 1 | 1.5 | Active High |  |  | MSOP
TPS2066A - Two-Channel, Current-Limited, Power-Distribution Switches | 4.5 | 5.5 | 1 | 1.9 | Active High | 0.81 | 250 | SON8 | no stock
TPS2066C - Dual-Channel, Current-Limited, Power-Distribution Switch | 4.5 | 5.5 | 1 | 1.12 to 2.10 | Active High |  |  | MSOP
TPS2066C-2 - Dual Channel Current Limiting Switch | 4.5 | 5.5 | 1 | 1.6 | Active High |  |  | MSOP
TPS2560 - Dual Channel Precision Adjustable Current-Limited Power Switches | 2.5 | 6.5 | 2.5 | 0.25 to 2.5 | Active Low | 0.92 | 250 | VSON10 | stock
TPS2560A - Dual Channel Precision Adjustable Current-Limited Power Switches | 2.5 | 6.5 | 2.5 | 0.25 to 2.5 | Active Low | 0.92 | 250 | VSON10 | stock
TPS2561 - Dual Channel Precision Adjustable Current-Limited Power Switches | 2.5 | 6.5 | 2.5 | 0.25 to 2.5 | Active High | 0.92 | 250 | VSON10 | good stock
TPS2561A - Dual Channel Precision Adjustable Current-Limited Power Switches | 2.5 | 6.5 | 2.5 | 0.25 to 2.5 | Active High | 0.92 | 250 | VSON10 | stock

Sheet: Ethernet Mappings
Pin | Signal |  |  |  |  |  |  |  | Net | X1 (mm) | Y1 (mm) |  | Net | X1 (mm) | Y1 (mm) |  | Net | X1 (mm) | Y1 (mm) | Net | Component | X1 (mm) | Y1 (mm) | Designator
P0_1 | ENET_COL |  | ENET_RXD0 | P1_15 | P1_18 | ENET_TXD0 |  | #N/A | P3_4 | 42.92 | 56.836 | #N/A | PD_12 | 60 | 37.2 | #N/A | PF_4 | 21.84 | 57.86 | LCD_VD20 | H1 | 19.3 | 51.99 | 8
P4_1 | ENET_COL |  | ENET_COL | P9_6 | P1_19 | ENET_TX_CLK |  | #N/A | PE_14 | 43.555 | 56.355 | #N/A | P6_0 | 60.1 | 38 | #N/A | WAKEUP0 | 21.205 | 57.895 | LCD_VD22 | H1 | 19.3 | 53.26 | 6
P9_6 | ENET_COL |  | ENET_TXD2 | P9_4 | P1_20 | ENET_TXD1 |  | #N/A | P7_0 | 44.19 | 55.924 | #N/A | CLK1 | 58.275 | 39.925 | #N/A | P3_7 | 23.745 | 57.855 | LCD_VD18 | H1 | 19.3 | 50.72 | 10
P1_16 | ENET_CRS |  | ENET_TXD3 | P9_5 | PD_11 | #N/A |  | #N/A | CLK2 | 44.825 | 55.555 | #N/A | PD_9 | 59.17 | 41.83 | #N/A | WAKEUP1 | 23.11 | 57.89 | 3V3 | H1 | 19.3 | 55.8 | 2
P9_0 | ENET_CRS |  | ENET_RXD3 | P9_2 | PD_8 | #N/A |  | #N/A | PE_12 | 45.46 | 55.532 | #N/A | PD_10 | 58.965 | 43.735 | #N/A | P3_8 | 22.475 | 57.825 | GND | H1 | 19.3 | 54.53 | 4
P2_0 | ENET_MDC |  | ENET_MDIO | P1_17 | P1_16 | ENET_RX_DV |  | #N/A | PE_11 | 46.095 | 55.226 | #N/A | CLK3 | 59.53 | 44.37 | #N/A | SAMPLE | 20.57 | 57.83 | LCD_VD12 | H1 | 19.3 | 46.91 | 16
P7_7 | ENET_MDC |  | #N/A | PD_6 | PD_7 | #N/A |  | #N/A | PE_10 | 46.73 | 54.92 | #N/A | PD_14 | 59.888 | 45.005 | #N/A | RTCX1 | 19.935 | 57.865 | LCD_VD10 | H1 | 19.3 | 45.64 | 18
PC_1 | ENET_MDC |  | #N/A | P1_5 | P9_3 | ENET_RXD2 |  | #N/A | PE_15 | 47.365 | 54.635 | #N/A | PD_13 | 59.825 | 46.275 | #N/A | RTCX2 | 19.3 | 57.9 | LCD_VD16 | H1 | 19.3 | 49.45 | 12
P1_17 | ENET_MDIO |  | ENET_CRS | P9_0 | PD_4 | #N/A |  | #N/A | PE_9 | 48 | 54.329 | #N/A | PD_16 | 59.89 | 46.91 | #N/A | RTC_ALARM | 25.015 | 56.953 | LCD_VD14 | H1 | 19.3 | 48.18 | 14
PC_0 | ENET_RX_CLK |  | #N/A | PD_5 | P1_4 | #N/A |  | #N/A | PE_8 | 48.635 | 54.223 | #N/A | PD_15 | 59.855 | 47.545 | #N/A | P3_5 | 24.38 | 56.22 | LCD_VD8 | H1 | 19.3 | 44.37 | 20
P1_16 | ENET_RX_DV |  | #N/A | PD_3 | P9_1 | ENET_RX_ER |  | #N/A | PE_7 | 49.27 | 54.038 | #N/A | PE_0 | 59.82 | 48.18 | #N/A | P3_2 | 29.46 | 56.23 | LCD_VD6 | H1 | 19.3 | 43.1 | 22
PC_8 | ENET_RX_DV |  | #N/A | P1_3 | P0_1 | ENET_TX_EN |  | #N/A | P3_0 | 49.925 | 53.873 | #N/A | P6_1 | 59.785 | 48.815 | #N/A | PF_5 | 28.19 | 56.134 | LCD_VD9 | H1 | 18.03 | 44.37 | 19
P9_1 | ENET_RX_ER |  | #N/A | PC_13 | P0_0 | ENET_RXD1 |  | #N/A | PE_13 | 50.54 | 53.668 | #N/A | P6_3 | 59.65 | 49.45 | #N/A | P3_3 | 27.555 | 56.109 | LCD_VD4 | H1 | 19.3 | 41.83 | 24
PC_9 | ENET_RX_ER |  | #N/A | PD_2 | PC_0 | ENET_RX_CLK |  | #N/A | PA_1 | 51.175 | 53.275 | #N/A | PE_1 | 59.615 | 50.085 | #N/A | PF_0 | 26.92 | 56.07 | LCD_FP | H1 | 19.3 | 38.02 | 30
P1_15 | ENET_RXD0 |  |  |  |  |  |  | #N/A | PA_2 | 51.81 | 53.19 | #N/A | P6_2 | 59.58 | 50.72 | #N/A | PF_1 | 26.285 | 56.045 | LCD_EN | H1 | 19.3 | 36.75 | 32
P0_0 | ENET_RXD1 |  |  |  |  |  |  | #N/A | P2_5 | 52.445 | 53.012 | #N/A | PA_0 | 59.545 | 51.355 | #N/A | PF_2 | 25.65 | 56.06 | LCD_VD2 | H1 | 19.3 | 40.56 | 26
P9_3 | ENET_RXD2 |  |  |  |  |  |  | #N/A | PE_4 | 53.08 | 52.88 | #N/A | P2_4 | 41.59 | 51.99 | #N/A | P3_6 | 25.015 | 56.135 | LCD_VD0 | H1 | 19.3 | 39.29 | 28
PC_6 | ENET_RXD2 |  |  |  |  |  |  | #N/A | I2C0_SDA | 53.715 | 52.615 | #N/A | PE_3 | 41.854 | 52.625 | #N/A | PF_3 | 28.825 | 56.159 | PF_6 | H1 | 19.3 | 34.21 | 36
P9_2 | ENET_RXD3 |  |  |  |  |  |  | #N/A | I2C0_SCL | 54.35 | 52.25 | #N/A | P2_3 | 42.102 | 53.26 |  |  |  |  | WAKEUP2 | H1 | 19.3 | 35.48 | 34
PC_7 | ENET_RXD3 |  |  |  |  |  |  | #N/A | PE_6 | 55 | 52.157 | #N/A | P6_7 | 42.337 | 53.895 |  |  |  |  | PF_7 | H1 | 19.3 | 32.94 | 38
P1_19 | ENET_TX_CLK |  |  |  |  |  |  | #N/A | P6_6 | 55.62 | 51.92 | #N/A | PA_3 | 42.599 | 54.53 |  |  |  |  | P8_1 | H1 | 19.3 | 31.67 | 40
P0_1 | ENET_TX_EN |  |  |  |  |  |  | #N/A | PE_5 | 56.255 | 51.655 |  |  |  |  |  |  |  |  | ADC0_6 | H1 | 19.3 | 27.86 | 46
PC_4 | ENET_TX_EN |  |  |  |  |  |  | #N/A | PE_2 | 56.89 | 51.19 |  |  |  |  |  |  |  |  | ADC0_5 | H1 | 19.3 | 21.51 | 56
CLK0 | ENET_TX_ER | Not Used |  |  |  |  |  | #N/A | P3_1 | 57.525 | 57.465 |  |  |  |  |  |  |  |  | P8_2 | H1 | 19.3 | 30.4 | 42
PC_14 | ENET_TX_ER |  |  |  |  |  |  | #N/A | PA_4 | 58.2 | 57 |  |  |  |  |  |  |  |  | PF_8 | H1 | 19.3 | 29.13 | 44
PC_5 | ENET_TX_ER |  |  |  |  |  |  |  |  |  |  |  |  |  |  |  |  |  |  | ADC0_2 | H1 | 19.3 | 26.59 | 48
P1_18 | ENET_TXD0 |  | H5 (Bottom Right) |  |  |  |  | H3 (Top Right) |  |  |  | H4 (Right Side) |  |  |  | H2 (Top Left) |  |  |  | ADC0_7 | H1 | 19.3 | 25.32 | 50
P1_20 | ENET_TXD1 |  |  |  |  |  |  |  |  |  |  |  |  |  |  |  |  |  |  | ADC0_3 | H1 | 18.03 | 29.13 | 43
P9_4 | ENET_TXD2 |  |  |  |  |  |  |  |  |  |  |  |  |  |  |  |  |  |  | ADC0_4 | H1 | 18.03 | 27.86 | 45
PC_2 | ENET_TXD2 |  |  |  |  |  |  |  |  |  |  |  |  |  |  |  |  |  |  | GNDA | H1 | 19.3 | 20.24 | 58
P9_5 | ENET_TXD3 |  |  |  |  |  |  |  |  |  |  |  |  |  |  |  |  |  |  | PC_14 | H1 | 19.3 | 18.97 | 60
PC_3 | ENET_TXD3 |  |  |  |  |  |  |  |  |  |  |  |  |  |  |  |  |  |  | ADC0_0 | H1 | 19.3 | 24.05 | 52
 |  |  |  |  |  |  |  |  |  |  |  |  |  |  |  |  |  |  |  | P4_0 | H1 | 19.3 | 22.78 | 54
 |  |  |  |  |  |  |  |  |  |  |  |  |  |  |  |  |  |  |  | LCD_VD23 | H1 | 18.03 | 53.26 | 5
 |  |  |  |  |  |  |  |  |  |  |  |  |  |  |  |  |  |  |  | GND | H1 | 18.03 | 54.53 | 3
 |  |  |  |  |  |  |  |  |  |  |  |  |  |  |  |  |  |  |  | LCD_VD21 | H1 | 18.03 | 51.99 | 7
 |  |  | ENET_MDC | PC_1 |  |  |  |  |  |  |  |  |  |  |  |  |  |  |  | GND | H1 | 18.03 | 55.8 | 1
 |  |  |  |  |  |  |  |  |  |  |  |  |  |  |  |  |  |  |  | LCD_VD15 | H1 | 18.03 | 48.18 | 13
 |  |  |  |  |  |  |  |  |  |  |  |  |  |  |  |  |  |  |  | LCD_VD3 | H1 | 18.03 | 40.56 | 25
 |  |  |  |  |  | ULPI_D7 | PB_2 | B12 |  |  |  |  |  |  |  |  |  |  |  | LCD_VD19 | H1 | 18.03 | 50.72 | 9
 |  |  |  |  |  | ULPI_D7 | PC_1 |  |  |  |  |  |  |  |  |  |  |  |  | LCD_VD17 | H1 | 18.03 | 49.45 | 11
 |  |  |  |  |  |  |  |  |  |  |  |  |  |  |  |  |  |  |  | LCD_VD13 | H1 | 18.03 | 46.91 | 15
 |  |  |  |  |  |  |  |  |  |  |  |  |  |  |  |  |  |  |  | LCD_VD11 | H1 | 18.03 | 45.64 | 17
 |  |  |  |  |  | LCD_VD21 | P4_3 |  |  |  |  |  |  |  |  |  |  |  |  | LCD_VD1 | H1 | 18.03 | 39.29 | 27
 |  |  |  |  |  | LCD_VD21 | PB_2 |  |  |  |  |  |  |  |  |  |  |  |  | GND | H1 | 18.03 | 38.02 | 29
 |  |  |  |  |  |  |  |  |  |  |  |  |  |  |  |  |  |  |  | LCD_VD7 | H1 | 18.03 | 43.1 | 21
 |  |  |  |  |  |  |  |  |  |  |  |  |  |  |  |  |  |  |  | LCD_VD5 | H1 | 18.03 | 41.83 | 23
 |  |  |  |  |  |  |  |  |  |  |  |  |  |  |  |  |  |  |  | GND | H1 | 18.03 | 35.48 | 33
 |  |  |  |  |  |  |  |  |  |  |  |  |  |  |  |  |  |  |  | P7_6 | H1 | 18.03 | 32.94 | 37
 |  |  |  |  |  |  |  |  |  |  |  |  |  |  |  |  |  |  |  | LCD_DCLK | H1 | 18.03 | 36.75 | 31
 |  |  |  |  |  |  |  |  |  |  |  |  |  |  |  |  |  |  |  | P8_0 | H1 | 18.03 | 31.67 | 39
 |  |  |  |  |  |  |  |  |  |  |  |  |  |  |  |  |  |  |  | P7_7 | H1 | 18.03 | 30.4 | 41
 |  |  |  |  |  |  |  |  |  |  |  |  |  |  |  |  |  |  |  | PF_9 | H1 | 18.03 | 26.59 | 47
 |  |  |  |  |  |  |  |  |  |  |  |  |  |  |  |  |  |  |  | ADC0_1 | H1 | 18.03 | 25.32 | 49
 |  |  |  |  |  |  |  |  |  |  |  |  |  |  |  |  |  |  |  | PF_10 | H1 | 18.03 | 24.05 | 51
 |  |  |  |  |  |  |  |  |  |  |  |  |  |  |  |  |  |  |  | WAKEUP3 | H1 | 18.03 | 34.21 | 35
 |  |  |  |  |  |  |  |  |  |  |  |  |  |  |  |  |  |  |  | PF_11 | H1 | 18.03 | 20.24 | 57
 |  |  |  |  |  |  |  |  |  |  |  |  |  |  |  |  |  |  |  | P8_8 | H1 | 18.03 | 18.97 | 59
 |  |  |  |  |  |  |  |  |  |  |  |  |  |  |  |  |  |  |  | PD_0 | H1 | 18.03 | 22.78 | 53
 |  |  |  |  |  |  |  |  |  |  |  |  |  |  |  |  |  |  |  | PD_1 | H1 | 18.03 | 21.51 | 55

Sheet: LCD Pin Mapping
TFT 24 bit
External | LPC43xx | LCD
pin | pin used | function
LCD_VD23 | PB_0 | BLUE7
LCD_VD22 | PB_1 | BLUE6
LCD_VD21 | PB_2 | BLUE5
LCD_VD20 | PB_3 | BLUE4
LCD_VD19 | P7_1 | BLUE3
LCD_VD18 | P7_2 | BLUE2
LCD_VD17 | P7_3 | BLUE1
LCD_VD16 | P7_4 | BLUE0
LCD_VD15 | PB_4 | GREEN7
LCD_VD14 | PB_5 | GREEN6
LCD_VD13 | PB_6 | GREEN5
LCD_VD12 | P8_3 | GREEN4
LCD_VD11 | P4_9 | GREEN3
LCD_VD10 | P4_10 | GREEN2
LCD_VD9 | P4_8 | GREEN1
LCD_VD8 | P7_5 | GREEN0
LCD_VD7 | P8_4 | RED7
LCD_VD6 | P8_5 | RED6
LCD_VD5 | P8_6 | RED5
LCD_VD4 | P8_7 | RED4
LCD_VD3 | P4_2 | RED3
LCD_VD2 | P4_3 | RED2
LCD_VD1 | P4_4 | RED1
LCD_VD0 | P4_1 | RED0
LCD_LP | P7_6 | LCDLP
LCD_ENAB/LCDM | P4_6 | LCDENAB/LCDM
LCD_FP | P4_5 | LCDFP
LCD_DCLK | P4_7 | LCDDCLK
LCD_LE | P7_0 | LCDLE
LCD_PWR | P7_7 | LCDPWR
GP_CLKIN | PF_4 | LCDCLKIN

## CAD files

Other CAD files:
Design/Electrical/TextTest.dwg

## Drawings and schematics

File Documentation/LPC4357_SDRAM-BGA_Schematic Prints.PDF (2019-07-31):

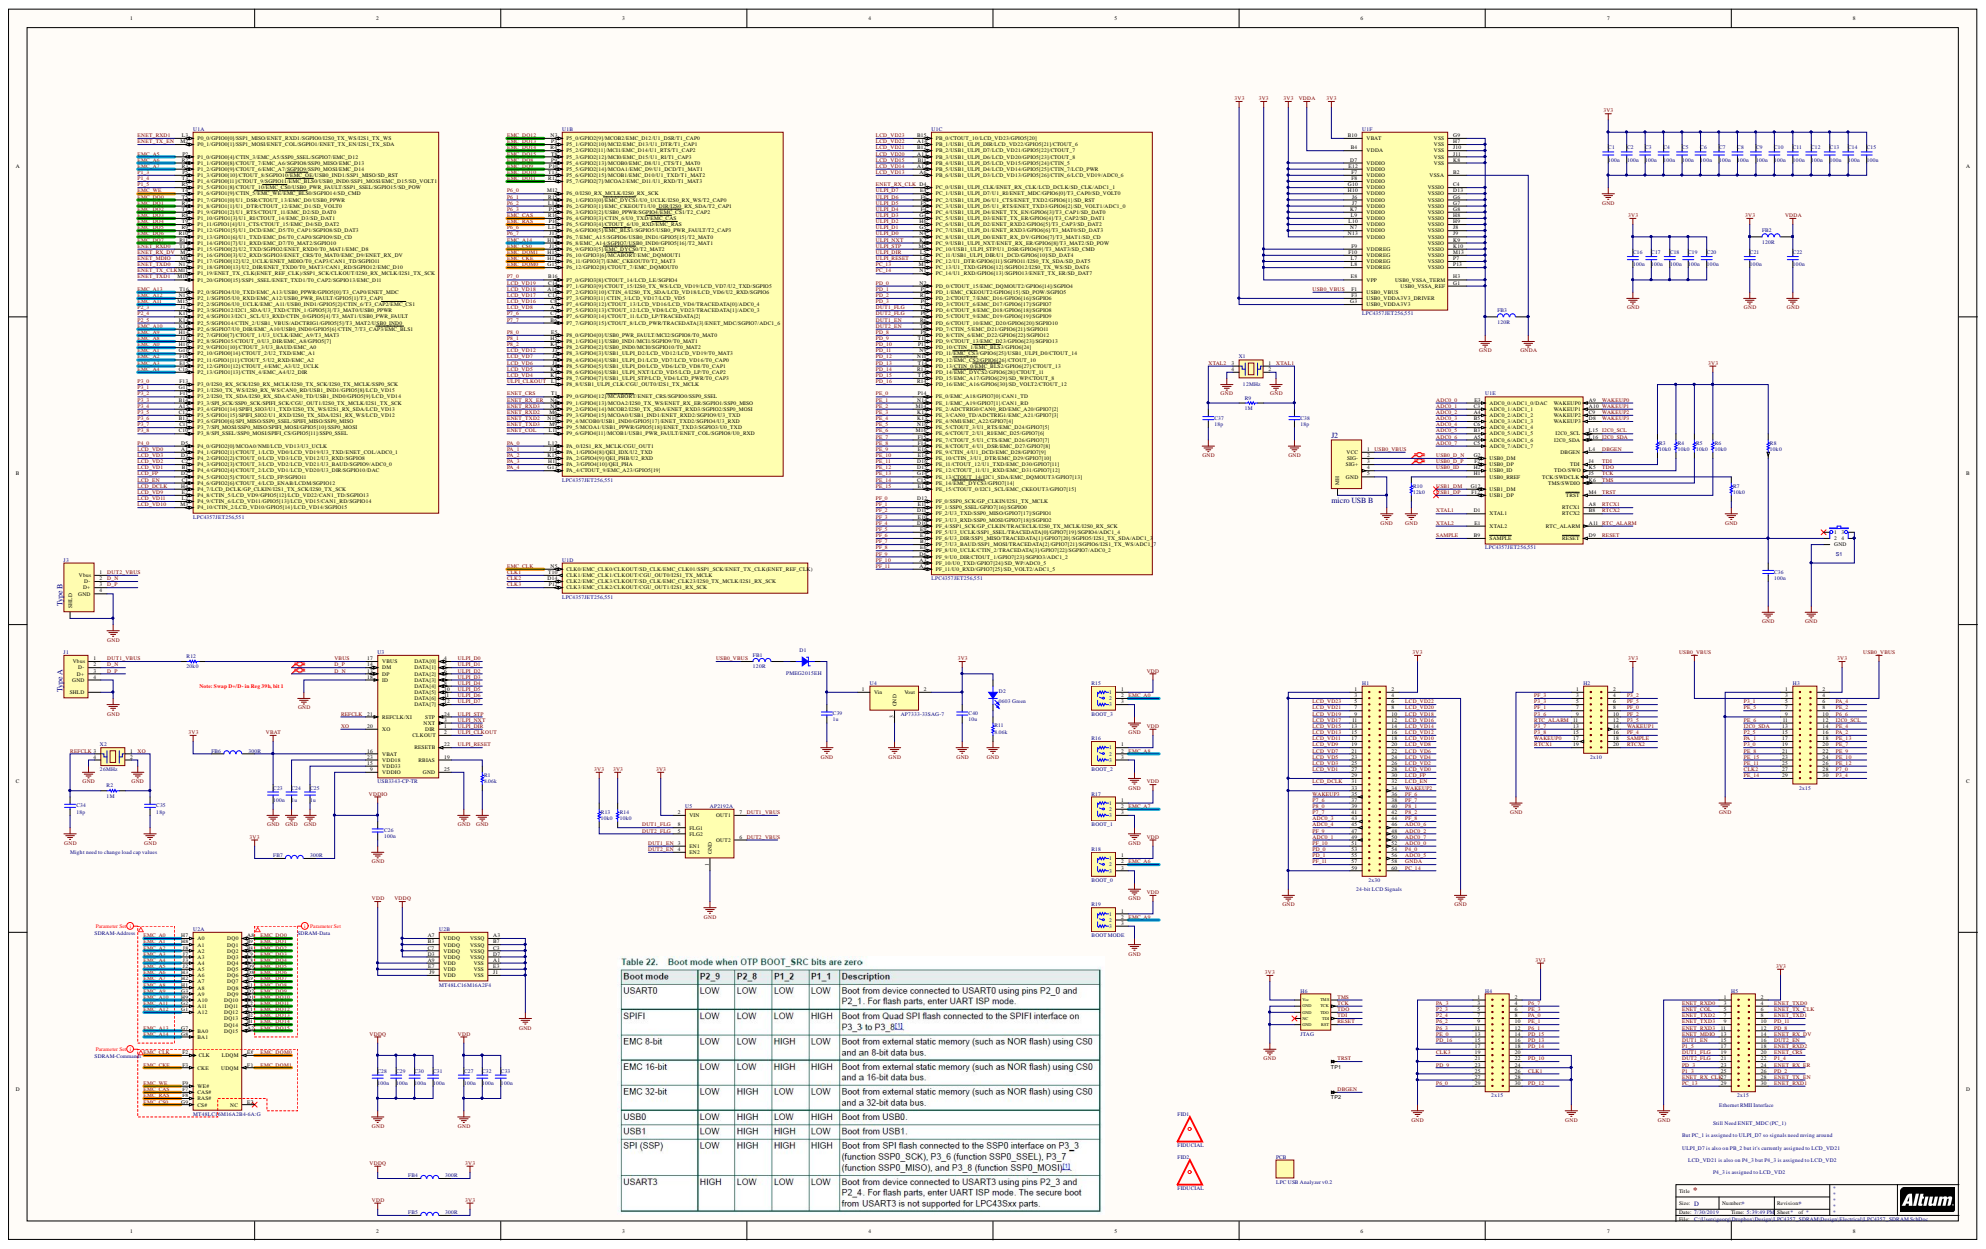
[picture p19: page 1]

Note: Swap D+/D- in Reg 39h, bit 1

Might need to change load cap values

But PC_1 is assigned to ULPI_D7 so signals need mving around

ULPI_D7 is also on PB_2 but it's currently assigned to LCD_VD21

LCD_VD21 is also on P4_3 but P4_3 is assigned to LCD_VD2

Title
C:\Users\georg\Dropbox\Design\LPC4357_SDRAM\Design\Electrical\LPC4357_SDRAM.SchDoc
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

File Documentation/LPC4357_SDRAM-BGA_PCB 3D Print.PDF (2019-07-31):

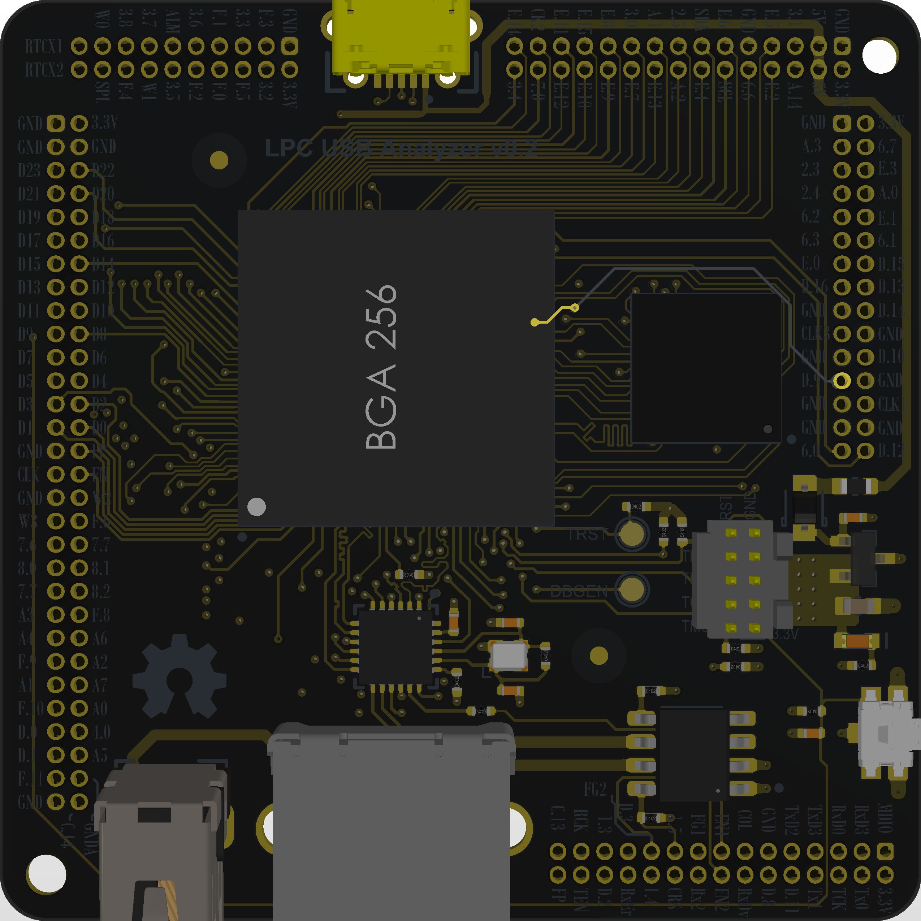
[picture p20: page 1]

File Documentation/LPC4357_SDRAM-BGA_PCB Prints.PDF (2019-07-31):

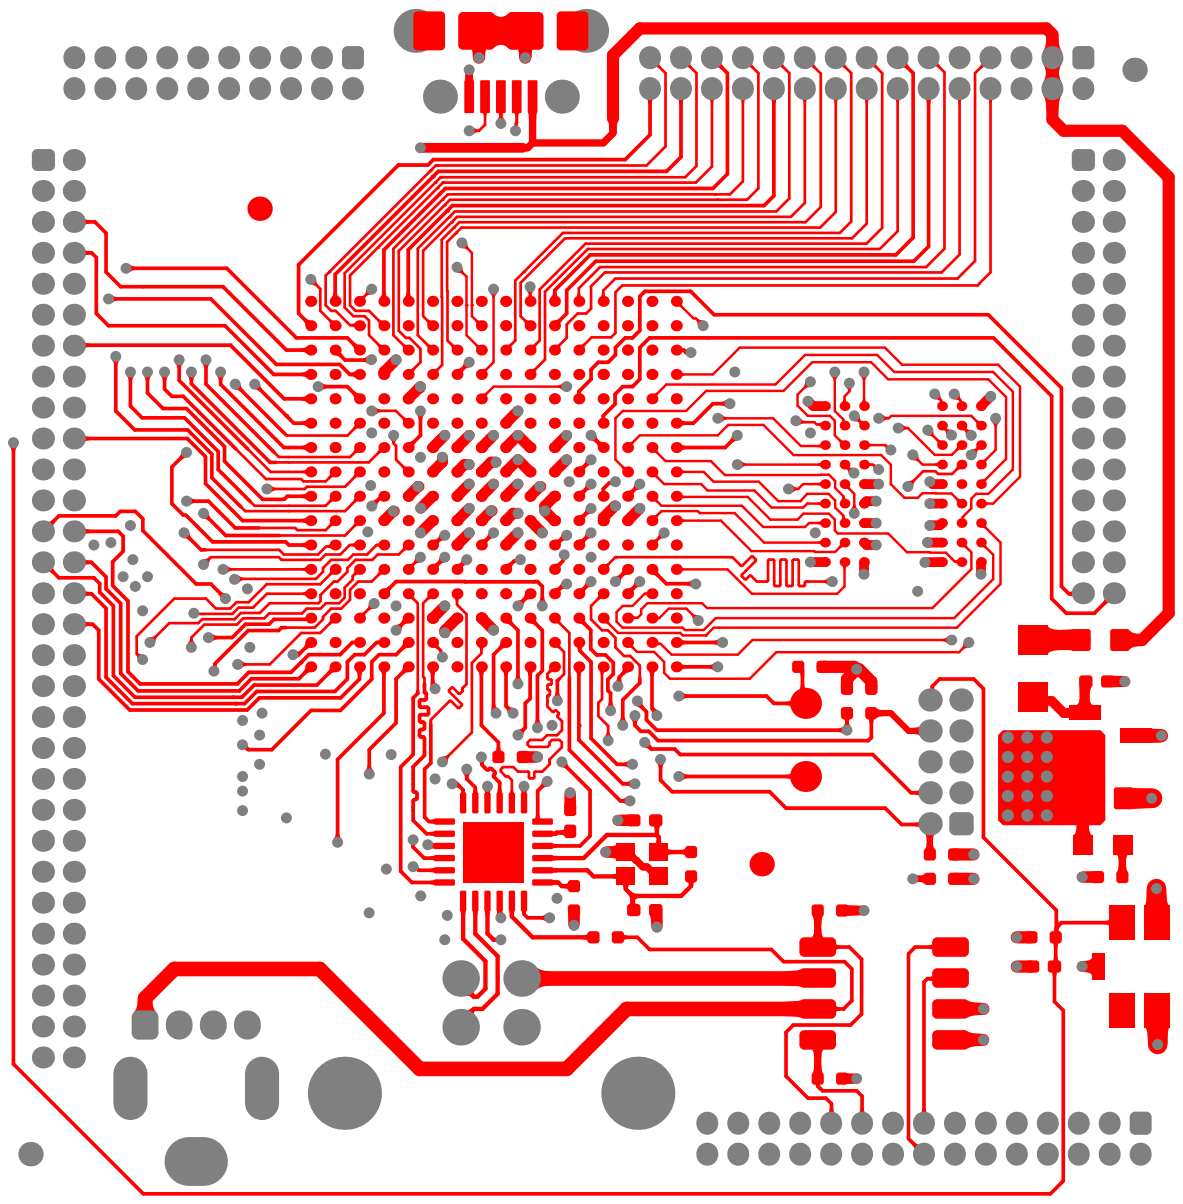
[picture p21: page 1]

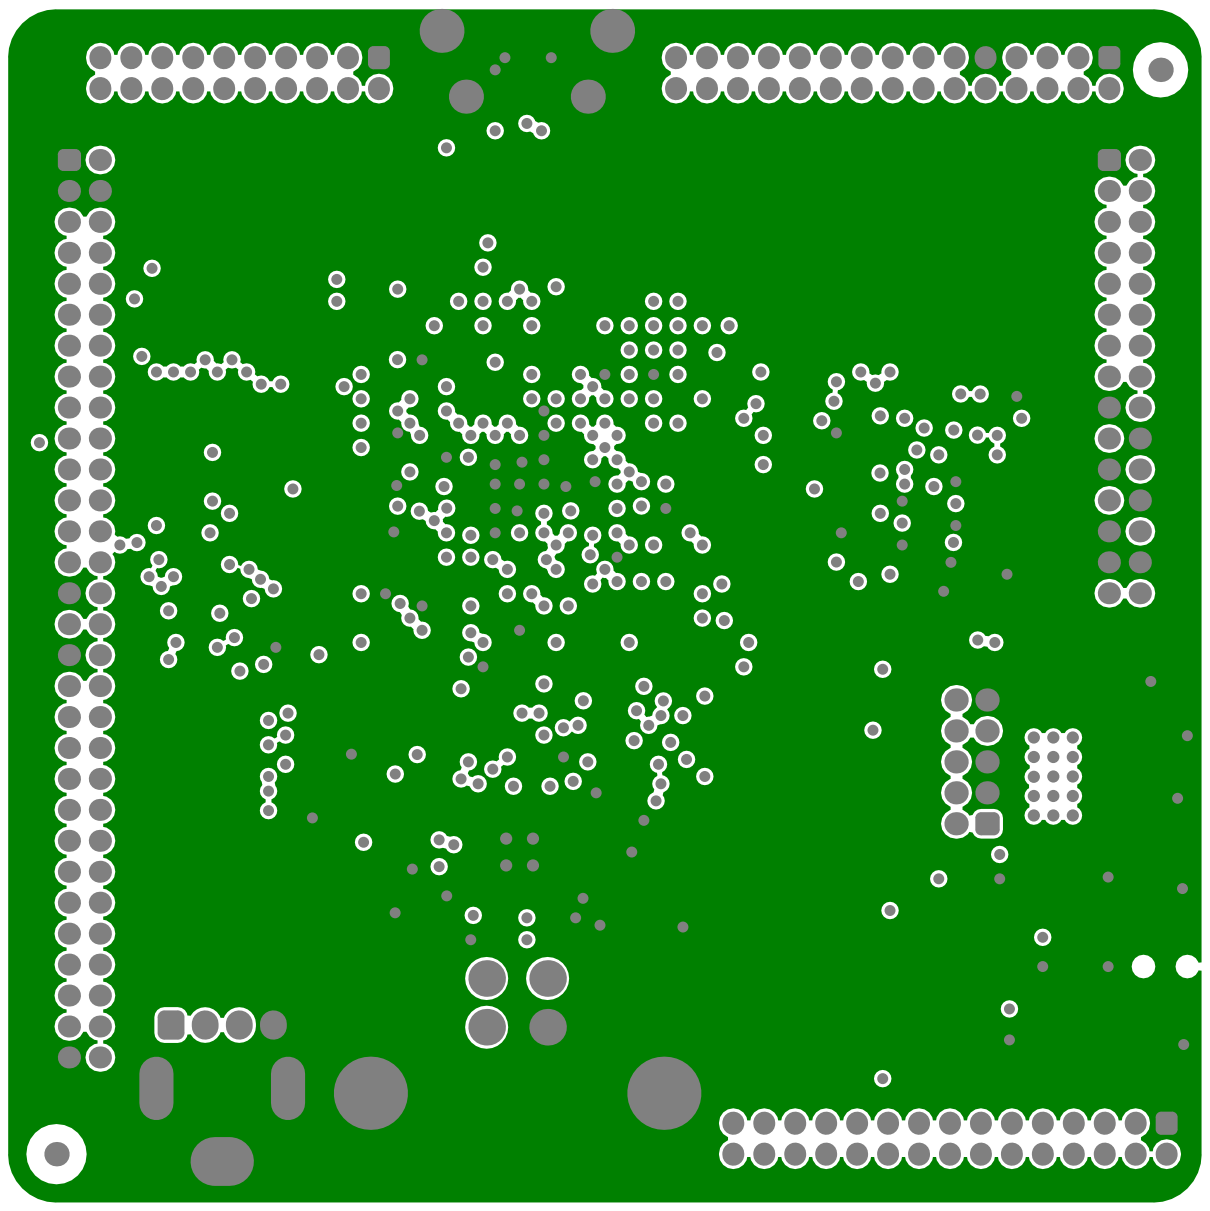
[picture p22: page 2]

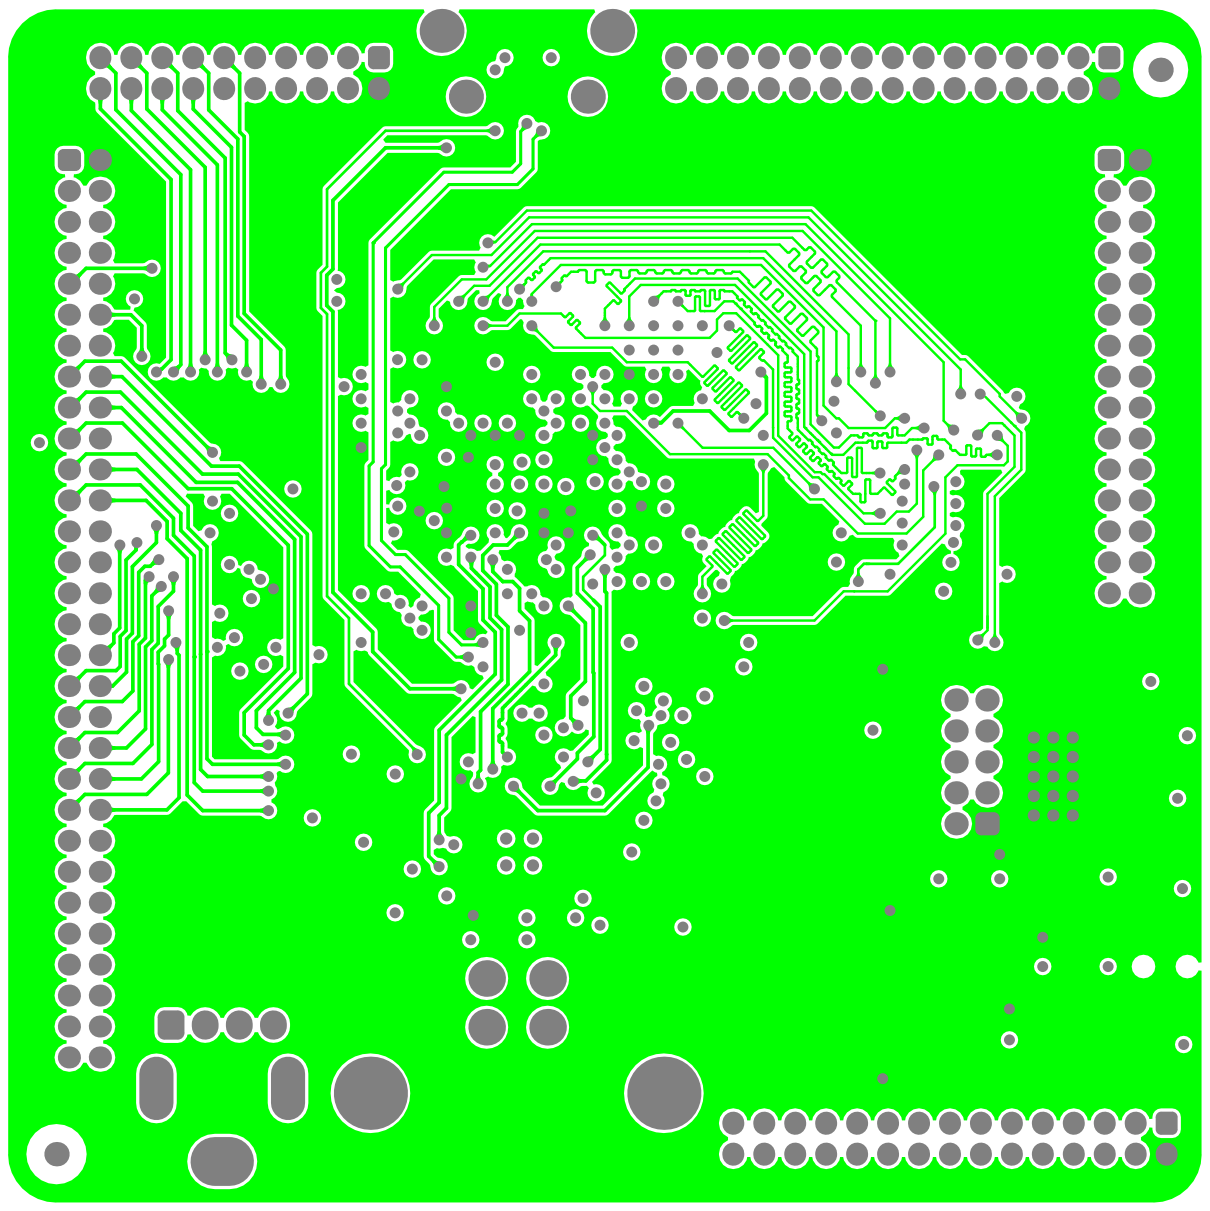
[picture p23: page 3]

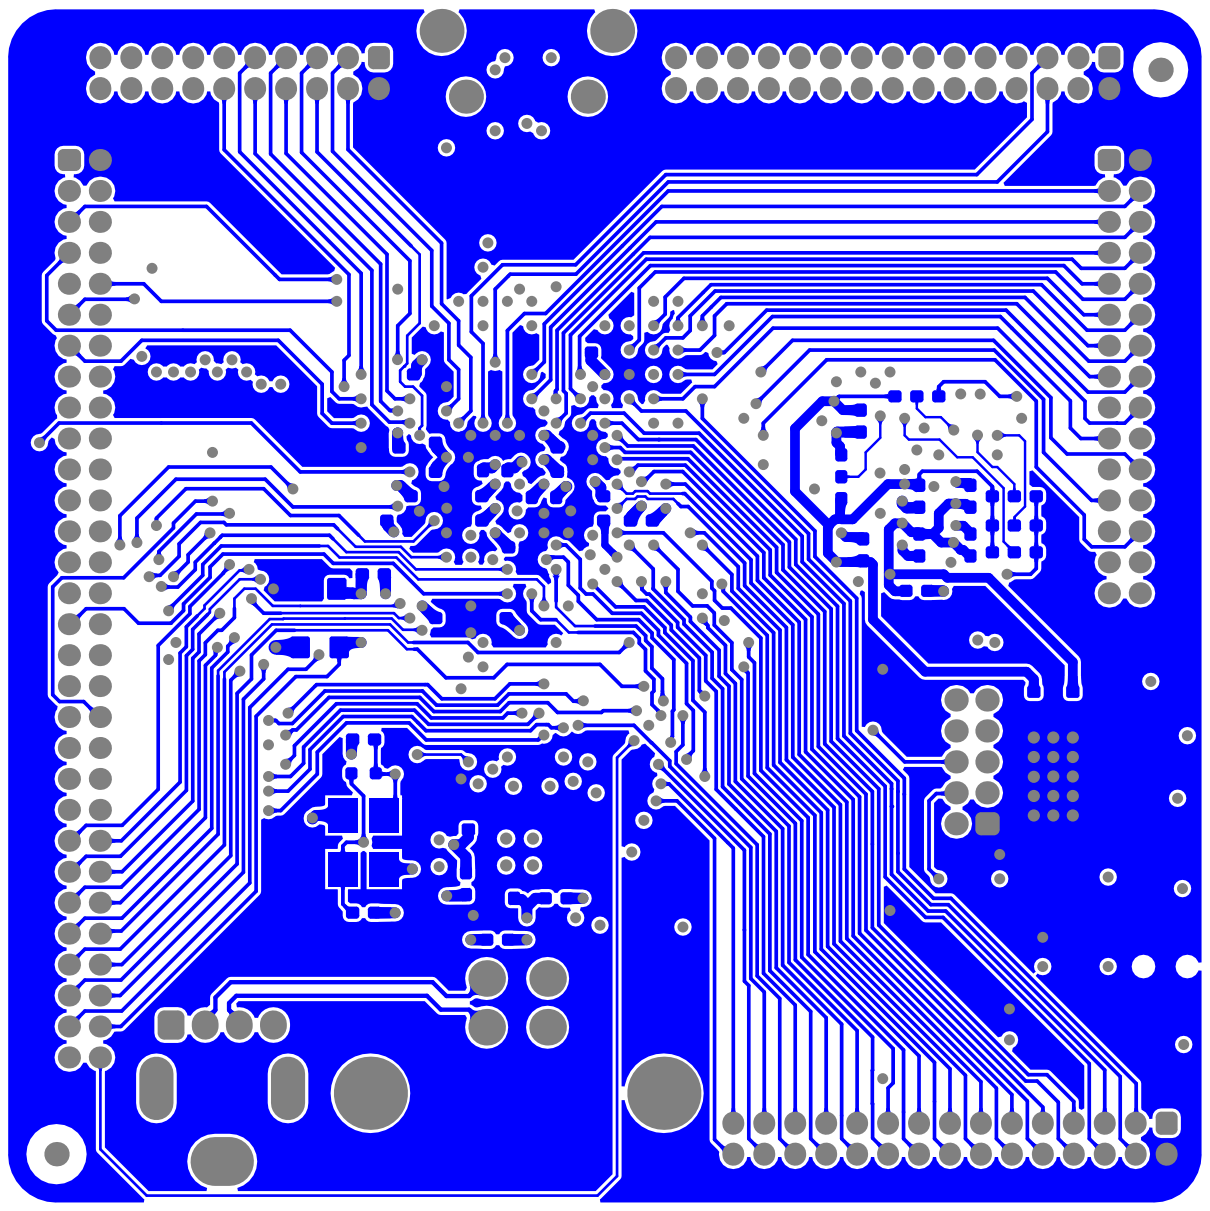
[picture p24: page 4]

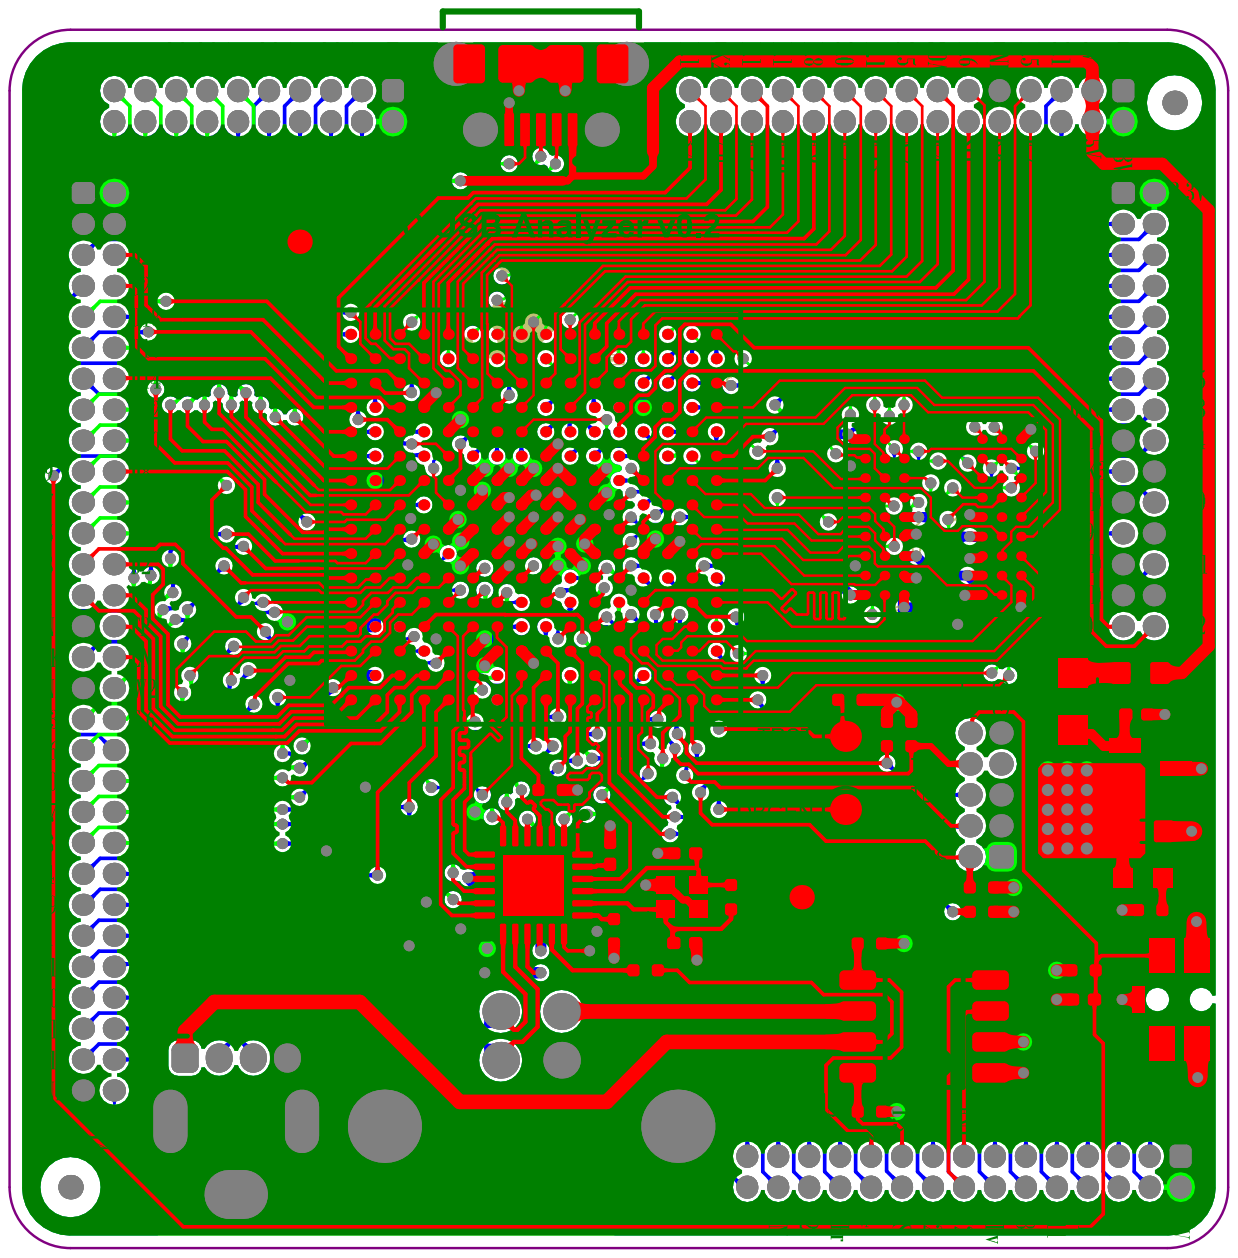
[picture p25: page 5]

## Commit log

2019-07-19 Initial Public Release
    [Header Net Routing Order.xlsx, LPC4357_SDRAM-BGA.PrjPcb, LPC4357_SDRAM.SchDoc]
2019-07-22 Added 2nd parallel USB Port Added USB Power switch Added Reset Button and Power LED Improved trace length matching on SDRAM signals
    [LPC4357_SDRAM-BGA.PrjPcb, LPC4357_SDRAM.SchDoc]
2019-07-22 Design Additions and Improvements
    Added 2nd parallel USB B Connector
    Added USB Power Switch
    Added Reset Button and Power LED
    Improvements to SDRAM trace length matching
    Generated Output Files
    [Bill of Materials-LPC4357_SDRAM-BGA.xls, Header Pin Mappings.xlsx, LPC4357_SDRAM-BGA.PrjPcb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]
2019-07-22 Minor Tweaks
    Just some last minute cleanup.
    Still need to decide what goes on silk screen
    [Bill of Materials-LPC4357_SDRAM-BGA.xls, LPC4357_SDRAM-BGA.PrjPcb, LPC4357_SDRAM.SchDoc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]
2019-07-28 Ready for Prototype
    Added Boot Mode Pin Jumpers on Bottom Layer
    Added Fiducials
    Added 1 locator pin hole and 1 M2 hole so board could go into a case
    More trace length cleanups and length matching
    Generated Output files
    [Bill of Materials-LPC4357_SDRAM-BGA.xls, LPC4357_SDRAM-BGA.PrjPcb, LPC4357_SDRAM.SchDoc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]
2019-07-31 Minor Changes Before Release
    Mostly just changes to go with reducing soldermask expansion from 4mil to 3mil to make it a little less “thieving”
    [Bill of Materials-LPC4357_SDRAM-BGA.xls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]
2019-08-01 Minor Changes for Part Ordering
    [Bill of Materials-LPC4357_SDRAM-BGA.xls, LCSC_Exported_20190801_013025.xlsx, LPC4357_SDRAM-BGA.PrjPcb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]
2021-06-02 Adding X-Rays
    [Bill of Materials-LPC4357_SDRAM-BGA.xls, LPC4357_SDRAM-BGA.PrjPcb, Pick Place for LPC4357_SDRAM_v0.2.csv]
